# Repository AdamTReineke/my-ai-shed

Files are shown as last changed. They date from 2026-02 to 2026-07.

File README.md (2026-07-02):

# My AI Shed

## A 12x16 Shed, primarily designed by Claude

I'm building a shed and this repository documents the design.

A photo of the shed from April 13, 2026

## Table of Contents

- [0 — Shed Design](docs/0-readme.md)
- [1 — Pier Design & As-Built Details](docs/1-piers.md)
- [2 — Beam](docs/2-beam.md)
- [3 — Floor Joists](docs/3-joists.md)
- [4 — Wall Framing](docs/4-walls.md)
- [5 — Wall Assembly Layers](docs/5-wall-layers.md)
- [6 — Trusses (Queen-Post Design)](docs/6-trusses.md)
- [7 — Roof](docs/7-roof.md)
- [8 — Fastener Schedule](docs/8-fasteners.md)
- [9 — Interior Finishings](docs/9-finishings.md)
- [10 — Stairs & Landing](docs/10-stairs.md)
- [11 — Trades & Mechanical](docs/11-trades.md)
- [12 — Metal Roof](docs/12-metal-roof.md)
- [13 — Siding Installation](docs/13-siding.md)
- [A1 — Errata & Documentation Inconsistencies](docs/A1-errata.md)
- [A2 — Eaves & Overhangs](docs/A2-eaves-proposal.md)
- [A3 — Batten & Purlin Grid](docs/A3-purlin-proposal.md)
- [Images](images.md)

## Screenshots of the Model

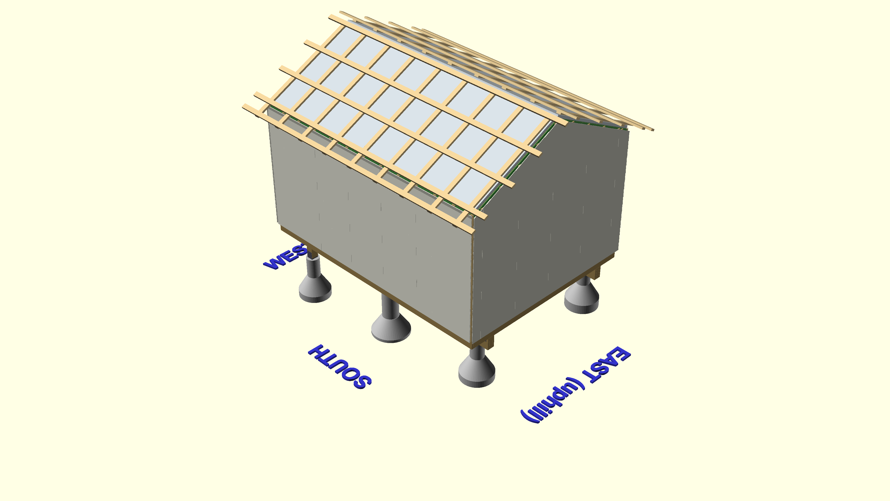
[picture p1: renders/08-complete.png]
screenshot of the OpenSCAD rendering of the shed


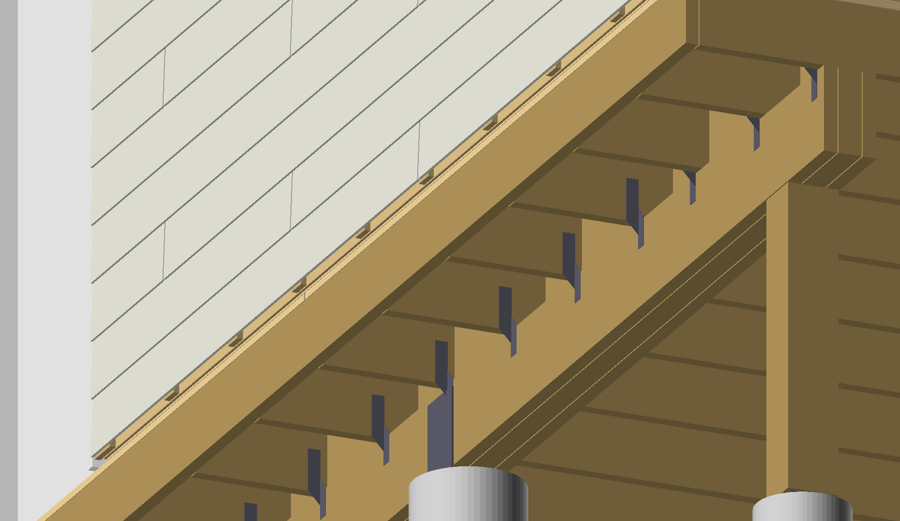
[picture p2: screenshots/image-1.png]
screenshot from below the floor plane showing some of the joist layout, ties, etc and the siding on the walls


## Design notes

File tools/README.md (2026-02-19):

# Tools

Node.js scripts for generating data files and processing output. Run from the project root (`shed/`).

## siding-cuts.js

Generates the HardiePlank lap siding cut list.

```bash
node tools/siding-cuts.js             # print cut list to console
node tools/siding-cuts.js --json      # JSON output
node tools/siding-cuts.js --scad      # also writes model/siding_data.scad
```

## generate-truss-data.js

Generates polyhedron geometry for the queen-post trusses. Output is used by `model/trusses.scad`.

```bash
node tools/generate-truss-data.js     # writes model/truss_data.scad
```

## generate-end-truss-data.js

Generates polyhedron geometry for the end trusses and gable ladder framing. Output is used by `model/trusses.scad`.

```bash
node tools/generate-end-truss-data.js  # writes model/end_truss_data.scad
```

## parse-cutlist.js

Parses OpenSCAD console output (captured to `model/openscad-output.txt`) and aggregates the cut list into `model/cutlist.csv`.

```bash
node tools/parse-cutlist.js
```

To capture OpenSCAD output: run OpenSCAD with the echo statements enabled, copy the console output to `model/openscad-output.txt`, then run this script.

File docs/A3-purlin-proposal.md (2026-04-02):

# A3 — Batten & Purlin Grid

This document describes the two-layer roof grid that sits on top of the insulated Zip roof deck. It assumes the Zip sheathing and 2" polyiso foam are already installed per A2.

**Assembly order**: Zip roof deck → 2" polyiso (A2) → **battens → purlins** → metal roofing

---

## Coordinate System & Key Dimensions

| Reference | Value |
|---|---|
| Shed length (E-W) | 192" (16') |
| Shed width (N-S) | 144" (12') |
| Roof pitch | 6/12 (26.57°) |
| Rafter slope length (wall face to ridge) | 80.5" |
| Truss spacing | 24" o.c., 9 trusses |
| Target overhang (all sides) | 12" horizontal |

---

## Layer 1: Battens (up the slope, aligned with trusses)

Battens are the vertical members running from near the ridge down past the wall. They sit directly on the foam.

| Parameter | Value |
|---|---|
| Material | 2×4 SPF, installed **flat** (3.5" wide, 1.5" tall) |
| Orientation | Up the slope (parallel to rafters) |
| Spacing | 24" o.c., aligned with truss X positions |
| Ridge end | Stops **3" short of peak** (horizontal), ~3.4" along slope |
| Eave end | Extends **12" past wall** (horizontal), ~13.4" along slope |
| End battens | Inset so outer edge aligns with outer wall edge |
| Count | 9 per slope × 2 slopes = **18 battens** |

### Batten Length

```
slope_length = 72" / cos(26.57°) = 80.5"
ridge_gap_slope = 3" / cos(26.57°) = 3.4"
overhang_slope = 12" / cos(26.57°) = 13.4"
batten_length = 80.5" - 3.4" + 13.4" = 90.5"
```

~90.5" per batten — fits in 8' stock.

### Batten Attachment

- **Fastener**: #10 × 6" structural screws (e.g., GRK RSS)
- **Penetration**: 1.5" (batten) + 2" (foam) + 7/16" (Zip) + 2.0" (rafter bite) = 6.0"
- **Pattern**: 2 screws per batten where it crosses the rafter below (one crossing per batten, since they're aligned)
- **Count**: 9 battens × 2 screws × 2 slopes = **36 screws**

---

## Layer 2: Purlins (E-W, over battens)

Purlins are the horizontal members running E-W across the battens. Metal roofing screws into these.

| Parameter | Value |
|---|---|
| Material | 2×4 SPF, installed **flat** (3.5" wide, 1.5" tall) |
| Orientation | E-W (parallel to ridge) |
| Length | Two boards per row, butt-joined at center truss (96" from west end) |
| E-W extension | 12" past each gable end (configurable) |
| Total span | 192" + 24" = **216"** per row (two ~108" boards) |

### Purlin Row Positions (5 per slope)

The 5 rows are positioned relative to the ridge along the slope:

| Row | Position | Role |
|-----|---|---|
| P1 (ridge) | 3.4" from peak | Flush with top of battens; ridge cap attachment |
| P2 | ridge + 1/3 span | Field support |
| P3 | ridge + 2/3 span | Field support |
| P4 (wall) | 80.5" (at wall edge) | Transition point; overlaps roof/wall junction |
| P5 (eave) | 93.9" (at batten ends) | Flush with bottom of battens; eave attachment |

Where **span** = wall_pos − ridge_pos = 80.5" − 3.4" = 77.1", so:
- P2 = 3.4" + 25.7" = **29.1"** from peak
- P3 = 3.4" + 51.4" = **54.8"** from peak

**5 rows per slope × 2 slopes = 10 purlin rows = 20 boards**

### Purlin Attachment

Purlins sit on top of battens and are screwed down at each crossing:

- **Fastener**: #10 × 3" exterior screws
- **Pattern**: 2 screws per purlin-batten crossing
- **Crossings**: 5 rows × 9 battens × 2 slopes = 90 crossings
- **Count**: 90 × 2 = **180 screws**

---

## Plan View — One Slope

```
                    WEST                                          EAST
                    ←12"→←──────────── 192" (16') ──────────────→←12"→

Ridge (P1)          ════════════════════════════════════════════════════
                    |    |    |    |    |    |    |    |    |    |
P2 (29.1")          ════════════════════════════════════════════════════
                    |    |    |    |    |    |    |    |    |    |
P3 (54.8")          ════════════════════════════════════════════════════
                    |    |    |    |    |    |    |    |    |    |
- - - - - - - - - - wall face (80.5" down slope) - - - - - - - - - - -
P4 (wall, 80.5")    ════════════════════════════════════════════════════
                    |    |    |    |    |    |    |    |    |    |
Eave (P5, 93.9")    ════════════════════════════════════════════════════
                    ↑    ↑                                  ↑    ↑
                  end  T2                                T8  end
                 batten                                    batten

═══ = purlins (E-W, horizontal)
 |  = battens (up slope, vertical)
```

---

## Section View — Full Assembly at Eave

```
Looking east at south eave:

                ↑ ridge direction
               /
    P3 ═══════/═══════════   (purlin, over battens)
    ║║║║║║║║║/║║║║║║║║║║║   (batten, 2×4 flat on foam)
    ▓▓▓▓▓▓▓/▓▓▓▓▓▓▓▓▓▓▓▓   (2" polyiso)
    ══════/═══════════════   (Zip roof deck)
    ─────/─────────────────   (rafter)
         /
    P4 ═/═══════════════     (purlin at wall line)
    ║║║/║║║║║║║║║║║║║║║║║
    ▓▓/▓▓▓▓▓▓▓▓▓▓▓▓▓▓▓▓╗
    ═/════════════════════╗
    /──────────────────────
                           ║ wall face
    P5 ════════════════    ║ (eave purlin, on batten tips)
    ║║║║║║║║║║║║║║║║║║    ║ (batten extends 12" past wall)
                        12" out
```

---

## Materials Summary

| Component | Material | Size | Qty | Notes |
|---|---|---|-----|---|
| Battens | 2×4 SPF | 8' | 18 | 9 per slope, ~90.5" each |
| Purlins | 2×4 SPF | 9' (butt-joined at center) | 20 | 5 rows × 2 slopes × 2 halves |
| Structural screws | #10 × 6" | — | 36 | Battens into rafters through foam |
| Exterior screws | #10 × 3" | — | 180 | Purlins into battens |
| Closure strips (eave) | Foam | 18' | 2 | Match metal panel profile |
| Closure strips (ridge) | Foam | 16' | 2 | Under ridge cap |
| Ridge cap | Metal (match panels) | 16' | ~2 pcs | Overlapping at center |

---

## Installation Sequence

1. **Mark truss positions** on foam surface (24" o.c. from east end)
2. **Install battens** — 2×4 flat on foam, aligned with each truss, screwed through foam into rafter with #10 × 6" screws. Stop 3" short of peak, extend 12" past wall.
3. **Install purlins P1–P5** — 2×4 flat over battens, running E-W. Two boards per row, butt-joined at center truss. Extend 12" past each gable end. Screw into battens with #10 × 3" screws.
4. **Install drip edge** (Type D/F at eaves for gutters)
5. **Install metal roofing** — panels run ridge to eave, screw into purlins
6. **Install rake drip edge** — over panel edges
7. **Install ridge cap** with closure strips

---

## Open Questions

1. **Metal roofing profile** — exposed fastener vs. standing seam determines exact purlin spacing requirements and closure strip profile.

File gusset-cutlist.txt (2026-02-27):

Gusset Plate Cut List - 1/2" Plywood (48"x96" sheets)
============================================================
Total pieces: 98 (14x 12x20, 84x 10x8)
Sheets required: 3

Sheet 1  (88.5% utilization)
  Summary: 14x 12x20, 9x 10x8
  Layout:
    12x20  at ( 0,  0)  cut 12"x20"
    12x20  at (12,  0)  cut 12"x20"
    12x20  at (24,  0)  cut 12"x20"
    12x20  at (36,  0)  cut 12"x20"
    12x20  at ( 0, 20)  cut 12"x20"
    12x20  at (12, 20)  cut 12"x20"
    12x20  at (24, 20)  cut 12"x20"
    12x20  at (36, 20)  cut 12"x20"
    12x20  at ( 0, 40)  cut 12"x20"
    12x20  at (12, 40)  cut 12"x20"
    12x20  at (24, 40)  cut 12"x20"
    12x20  at (36, 40)  cut 12"x20"
    12x20  at ( 0, 60)  cut 12"x20"
    12x20  at (12, 60)  cut 12"x20"
    10x8   at (24, 60)  cut 8"x10"
    10x8   at (32, 60)  cut 8"x10"
    10x8   at (40, 60)  cut 8"x10"
    10x8   at ( 0, 80)  cut 8"x10"
    10x8   at ( 8, 80)  cut 8"x10"
    10x8   at (16, 80)  cut 8"x10"
    10x8   at (24, 80)  cut 8"x10"
    10x8   at (32, 80)  cut 8"x10"
    10x8   at (40, 80)  cut 8"x10"

Sheet 2  (93.8% utilization)
  Summary: 54x 10x8
  Layout:
    10x8   at ( 0,  0)  cut 8"x10"
    10x8   at ( 8,  0)  cut 8"x10"
    10x8   at (16,  0)  cut 8"x10"
    10x8   at (24,  0)  cut 8"x10"
    10x8   at (32,  0)  cut 8"x10"
    10x8   at (40,  0)  cut 8"x10"
    10x8   at ( 0, 10)  cut 8"x10"
    10x8   at ( 8, 10)  cut 8"x10"
    10x8   at (16, 10)  cut 8"x10"
    10x8   at (24, 10)  cut 8"x10"
    10x8   at (32, 10)  cut 8"x10"
    10x8   at (40, 10)  cut 8"x10"
    10x8   at ( 0, 20)  cut 8"x10"
    10x8   at ( 8, 20)  cut 8"x10"
    10x8   at (16, 20)  cut 8"x10"
    10x8   at (24, 20)  cut 8"x10"
    10x8   at (32, 20)  cut 8"x10"
    10x8   at (40, 20)  cut 8"x10"
    10x8   at ( 0, 30)  cut 8"x10"
    10x8   at ( 8, 30)  cut 8"x10"
    10x8   at (16, 30)  cut 8"x10"
    10x8   at (24, 30)  cut 8"x10"
    10x8   at (32, 30)  cut 8"x10"
    10x8   at (40, 30)  cut 8"x10"
    10x8   at ( 0, 40)  cut 8"x10"
    10x8   at ( 8, 40)  cut 8"x10"
    10x8   at (16, 40)  cut 8"x10"
    10x8   at (24, 40)  cut 8"x10"
    10x8   at (32, 40)  cut 8"x10"
    10x8   at (40, 40)  cut 8"x10"
    10x8   at ( 0, 50)  cut 8"x10"
    10x8   at ( 8, 50)  cut 8"x10"
    10x8   at (16, 50)  cut 8"x10"
    10x8   at (24, 50)  cut 8"x10"
    10x8   at (32, 50)  cut 8"x10"
    10x8   at (40, 50)  cut 8"x10"
    10x8   at ( 0, 60)  cut 8"x10"
    10x8   at ( 8, 60)  cut 8"x10"
    10x8   at (16, 60)  cut 8"x10"
    10x8   at (24, 60)  cut 8"x10"
    10x8   at (32, 60)  cut 8"x10"
    10x8   at (40, 60)  cut 8"x10"
    10x8   at ( 0, 70)  cut 8"x10"
    10x8   at ( 8, 70)  cut 8"x10"
    10x8   at (16, 70)  cut 8"x10"
    10x8   at (24, 70)  cut 8"x10"
    10x8   at (32, 70)  cut 8"x10"
    10x8   at (40, 70)  cut 8"x10"
    10x8   at ( 0, 80)  cut 8"x10"
    10x8   at ( 8, 80)  cut 8"x10"
    10x8   at (16, 80)  cut 8"x10"
    10x8   at (24, 80)  cut 8"x10"
    10x8   at (32, 80)  cut 8"x10"
    10x8   at (40, 80)  cut 8"x10"

Sheet 3  (36.5% utilization)
  Summary: 21x 10x8
  Layout:
    10x8   at ( 0,  0)  cut 8"x10"
    10x8   at ( 8,  0)  cut 8"x10"
    10x8   at (16,  0)  cut 8"x10"
    10x8   at (24,  0)  cut 8"x10"
    10x8   at (32,  0)  cut 8"x10"
    10x8   at (40,  0)  cut 8"x10"
    10x8   at ( 0, 10)  cut 8"x10"
    10x8   at ( 8, 10)  cut 8"x10"
    10x8   at (16, 10)  cut 8"x10"
    10x8   at (24, 10)  cut 8"x10"
    10x8   at (32, 10)  cut 8"x10"
    10x8   at (40, 10)  cut 8"x10"
    10x8   at ( 0, 20)  cut 8"x10"
    10x8   at ( 8, 20)  cut 8"x10"
    10x8   at (16, 20)  cut 8"x10"
    10x8   at (24, 20)  cut 8"x10"
    10x8   at (32, 20)  cut 8"x10"
    10x8   at (40, 20)  cut 8"x10"
    10x8   at ( 0, 30)  cut 8"x10"
    10x8   at ( 8, 30)  cut 8"x10"
    10x8   at (16, 30)  cut 8"x10"

============================================================
Total sheet area: 96.0 sq ft
Used area:        70.0 sq ft
Waste:            26.0 sq ft (27.1%)

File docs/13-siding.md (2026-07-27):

# Siding Installation

Process guide for hanging the HardiePlank lap siding over the rainscreen. Design background is in [5-wall-layers.md](5-wall-layers.md); fastener spec is in [8-fasteners.md](8-fasteners.md) §16. Cut list comes from `node tools/siding-cuts.js`.

## Where This Starts

Assumed already done before siding day:

- [ ] Zip sheathing up on all four walls, all seams taped and rolled
- [ ] Door installed, trimmed, and caulked (✓ done — siding butts to the existing trim)
- [ ] Z-flashing (or peel-and-stick) at the base of the Zip, lapping down over the rim/bottom plate

## The Stack (inside → out)

```
Zip sheathing (WRB)
  → 1×3 PT furring, vertical @ 16" o.c. over studs   (¾" rainscreen gap)
    → bug mesh closing the bottom of the gap
      → ripped HardiePlank starter strip
        → HardiePlank lap siding, 6.25" exposure, blind-nailed
          → metal outside corners, one per corner per course
```

Total buildup off the Zip face: ¾" furring + 5/16" plank ≈ **1-1/16"**. Remember this number — every screw that mounts anything to the finished wall has to cross it before reaching wood.

---

## Step 1 — Furring (1×3 PT, vertical)

- One strip over **every stud line**, 16" o.c., plus a strip at each **corner** (both faces of the corner need an edge to nail to) and tight to each side of the **door trim**.
- Fasten with **#8 (or #9) × 2½"–3½" PT-rated screws** into the studs, ~16" o.c. vertically. Screws, not nails — the furring holds the whole siding plane ¾" off the wall, so wind suction loads it in withdrawal, and a screw lets you back a bowed strip out and reset it.
  - **Coating:** must be rated for ACQ/PT contact — 305 stainless, or a coated structural/deck screw carrying a PT rating (GRK, Spax, Deckmate). Plain steel and electro-galvanized corrode out. These screws never touch the fiber cement, so unlike the siding nails they don't have to be stainless.
  - **Length:** ¾" furring + 7/16" Zip = **1.19" before the stud**, so 2½" buys 1.31" of thread and 3½" buys 2.31". Anything in that band works; 3" is the spec in [8-fasteners.md](8-fasteners.md) §16 and the best all-rounder. Keep the longest screws for the field — at corners and door jambs you're driving near stud edges, where an over-long screw can exit the side or reach the door jamb.
  - Don't drop below a #8 shank — a trim-head screw's head is too small to hold ¾" PT against the wall under suction.
- Check the furring plane for flatness as you go — a bowed strip telegraphs through every course above it. Shim or swap bad strips now, not later.
- **Extra furring where butt joints land.** Every plank butt joint must be backed by a furring strip. The cut list puts joints on stud lines, so the standard layout covers it — but if you improvise a joint mid-bay, add a strip behind it first.
- **Mark gutter bracket and electrical box locations on the Zip now** (see Steps 6–7) and add backing before the siding hides everything.

Leave the top of the gap open — top venting differs by wall, see **Top-of-Wall Transitions** below. The bottom gets closed next.

## Step 2 — Bug Mesh at the Bottom

Close the bottom of the ¾" gap so it vents but doesn't host wasps:

- Run the mesh (Cor-A-Vent SV-3 or insect screen strip) along the bottom of the wall, spanning the gap between the Zip face and the back of the siding plane.
- If using screen roll rather than a rigid vent strip: staple one edge to the Zip just above the Z-flashing, wrap it forward under the furring bottoms, and let the siding's first course pin the front edge. Don't block the airflow — the mesh breathes, a solid closure doesn't.
- Trim flush; it shouldn't be visible below the finished siding.

## Step 3 — Rip the Starter Strip

The starter strip kicks the first course out to the same angle as every other course (each normal course sits on the 2" of plank below it; course 1 has nothing under it without a starter).

- Rip **1¼"-wide strips** from one HardiePlank. One 12' plank ripped into 6 strips yields 72 lf — the perimeter needs ~53 lf, so **one plank does the whole shed** with spare.
- Cut with a circular saw + fiber-cement (PCD) blade against a rip guide, **outdoors, upwind, with an N95/P100 on** — fiber cement dust is crystalline silica. Score-and-snap doesn't work well for long rips.
- Nail the strips along the very bottom of the furring, bottom edges flush with the furring bottoms, one nail per strip per furring line.

## Step 4 — Layout

- **Story pole / chalk lines:** mark course tops every **6.25"** up from the first-course line on the corner furring strips and snap lines, or make a story pole and transfer marks. 16 courses reach the top of the 8' wall (16 × 6.25" = 100", so the top course gets ripped down — see Step 5).
- **First course:** bottom edge hangs **~¼" below the starter strip** to form a drip over the Z-flashing. Keep the bottom edge at least 1" clear of any horizontal surface and 6" clear of grade (the floor is up on piers, so this should be automatic — verify at the low corner).
- **Level check:** the first course sets every course above it. Get it dead level with a laser or 8' level before nailing off.

## Step 5 — Hang the Planks

Work bottom-up, one course at a time around the building. The cut list (`node tools/siding-cuts.js`) gives every piece per wall per course with stagger already worked out — cut a few courses ahead, label the backs (`S-3-1` = south, course 3, piece 1).

**Nailing** (per [8-fasteners.md](8-fasteners.md) §16):
- **3" stainless ring-shank**, blind-nailed **1" down from the top edge**, at **every furring strip** (16" o.c.).
- Keep nails **⅜" or more from plank ends**.
- Drive **flush, not countersunk** — an overdriven nail crushes the fiber cement and loses holding power. Set the gun pressure on a scrap first.

**Butt joints:**
- Land on furring, **⅛" gap**, caulked with paintable sealant after hanging.
- Prime every field-cut end before the piece goes up (touch-up primer or exterior acrylic paint — cut edges are bare cement).

**Metal outside corners:**
- One corner piece **per corner per course** (64 total). Hang the planks on both adjoining walls first, stopping each plank ⅛" shy of the corner (the cut list already builds this in), then slip the corner cap over both plank ends and nail through its top flange. The next course's planks and cap cover the nailing.
- E/W wall planks wrap over the N/S wall buildup at corners — that's why E/W courses are 146⅞", not 144" (one plank + a short piece per course, per the cut list).

**North wall / door:**
- Planks butt to the existing door trim with a **⅛" caulked gap** — do not nail within 2" of the trim edge.
- Courses 0–12 are split by the door: long run west of the door (has a staggered butt joint), short 13⅜" pieces between door trim and the east corner. Courses 13–15 run over the door full-width.
- Confirm there's a **metal drip cap over the door head trim** before siding above it; the course above the door laps over the drip cap flange, with a ¼" air gap above the horizontal leg (don't caulk that gap — it drains).

**Top course (N/S eave walls):**
- 16 courses × 6.25" overshoots the 96" wall by ~4" — rip the top course to end at the top of the wall Zip. Top-of-gap detail: see **Top-of-Wall Transitions** below.
- A ripped top course loses its blind-nail zone: **face-nail** it (2 nails per furring, ¾" from the top edge), and dab the heads with sealant + touch-up paint.

**Gable ends (E/W walls):**
- The cut list covers only the 16 rectangular courses — the gable triangles are measure-in-place. Continue courses up the gable, cutting plank ends at the roof pitch angle (**6/12 = 26.6°**).
- Gable planks need furring backing on the end-truss framing — add vertical 1×3 over the gable studs/webs before starting the triangle.
- Hold the top cuts **~¾" below the rake underside** to form the exhaust slot — see **Top-of-Wall Transitions** below. Cut edges must be primed.

### Top-of-Wall Transitions (Rainscreen Exhaust)

The two wall types terminate differently because the overhangs are built differently (no rafter tails — the eave is battens extended past the wall over the polyiso, open soffit, per [A2-eaves-proposal.md](A2-eaves-proposal.md)).

**N/S eave walls — closure block between battens, sealed under P4.** The P4 purlin row lands directly over the wall line (per [A3-purlin-proposal.md](A3-purlin-proposal.md)). A block in each batten bay — face at the furring plane, top edge tight under P4 — terminates the siding, covers the exposed deck/foam edges, and seals the junction so the rainscreen exhaust turns inboard and vents at the ridge instead of spilling out under the open soffit:

```
   slope ↗  metal panel
  ═══════════════════════════════════
       [P4 purlin] ← at the wall line, on the battens
   batten ─────────────────────────►  extends 12" past wall
   ░░ 2" polyiso ░░│ ┌───┐
   ── Zip deck ────│¾│blk│ ← block fills the batten bay, top edge
      heel blocking│"│   │   beveled 26.6°, tight under P4
      / top plate  │g│   │
   wall Zip ──────►│a│───┘
                   │p├───┐
                   │ │sid│ ← ripped top course laps block bottom ~1",
                   │ │   │   face-nailed into the block
```

- Battens are 2×4 flat (3.5" wide) at 24" o.c., so the bays match the 2×2 eave-blocking cut list: **six 20.5" blocks + two 19.75" end blocks per wall** (16 total). Height is measure-in-place: from ~1" below the siding top line up to the underside of P4, top edge **beveled 26.6°** to seat flat under it. Likely 1×6 or 1×8 stock — PT like the furring, or primed.
- Install each block on **¾" spacers** (furring offcuts) with 3" screws into the heel blocking/top plate — its face lands flush with the furring plane. Ends can be toe-screwed into the batten sides. Do not fill the ¾" standoff — a block tight to the Zip corks the rainscreen.
- Exhaust path: up the wall gap → behind the block → inboard along the between-batten channel → under the panels to the ridge vent. The bay is closed on all sides (battens flanking, P4 above, block in front), so no air or bugs pass to/from the open soffit.
- **No bug screen needed** — the circuit is closed: bottom mesh in, ridge profile vent out. The only residual route is the panel corrugation flutes crossing over the top of P4 from the overhang — the same exposure the roof channel already has by design. Add a mesh strip behind the blocks if that bothers you.
- Run the ripped top siding course up over the block's bottom edge and **face-nail into the block** (it doubles as the top-course nailer). No caulk along the top edge.
- Bonus: the block shields the bare roof-deck and polyiso edges at the wall line from UV, mice, and woodpeckers.

**E/W gable ends — terminated slot vent under the rake.** The gable gap cannot join the roof channel — the Zip deck edge, foam edge, and butyl-sealed gable trim close it off at the rake. It's a dead-end circuit: intake at the bottom mesh, exhaust through a screened slot under the rake overhang:

- Cut furring tops parallel to the rake, **~¾" below the underside of the rake structure** (foam/batten edge, or barge board if installed).
- Cut the siding top edges to the same line — this leaves a continuous downward-facing slot under the 12" rake overhang. Rain-protected; anything that blows in drains out the bottom mesh.
- Screen the slot the same way — mesh stapled to the Zip, folded out over the furring tops.
- **Do not caulk** the siding-to-rake edge.

## Step 6 — Electrical Mounting Blocks (outlets & lights)

Install the siding mounting blocks **as the courses reach them**, not after:

1. Before siding (Step 1), confirm each box location has **solid backing** — a stud/furring line, or add a horizontal 1×3 block between furring strips (leave ½" drainage gaps at its ends so it doesn't dam the rainscreen).
2. Drill the wire penetration through the Zip, pull the cable, and **seal the penetration** with Zip tape or sealant — the WRB is the water barrier, not the block.
3. When the course row reaches the block height, fasten the block to the backing, then cut the surrounding planks to it with a **⅛" caulked gap** on sides and bottom.
4. **Flash the top:** the block's built-in flange or a strip of Zip tape/drip cap behind the course above, so water sheds over the block face rather than behind it.

## Step 7 — Gutters on the Wall

Wall-mounted brackets have two problems on a rainscreen wall: the fastener has to reach real wood, and it must not crush the siding into the ¾" air gap.

- **Land every bracket on a stud line** (which is also a furring line — 16" o.c.). Marks made on the Zip in Step 1 transfer up via the furring strips.
- **Fastener:** stainless or coated structural screw long enough for the buildup — 5/16" plank + ¾" furring + 7/16" Zip = 1.5" before wood, so a **3½"–4" screw** gets 2"+ into the stud.
- **Pre-drill the HardiePlank** at each screw location (fiber cement cracks if a lag wanders) and snug the screw until the bracket bears — **stop before the plank deflects**. Because the bracket lands over a furring strip, the sandwich is solid there; that's the whole reason for hitting the stud lines.
- Bed each bracket in a dab of exterior sealant and cap the screw heads with the same. Any hole through the siding that misses (there's always one) gets filled with sealant immediately.
- If a bracket must land between studs, add horizontal blocking behind the siding **before** that course goes up — there is no fixing this after.

## Step 8 — Caulk and Paint

- Caulk: all butt joints, siding-to-door-trim, siding-to-mounting-block sides/bottoms. **Do not caulk** the bottom of any lap, the gap above the door drip cap, or the top/bottom rainscreen vents — those all drain or breathe by design.
- Paint: planks come pre-primed; finish-coat all faces with exterior acrylic. Every field cut should already have primer from Step 5 — the finish coat goes over it.

---

## Cut List & Materials

Full per-piece cut list: `node tools/siding-cuts.js` (77 stock planks, 141 pieces, stagger and corner gaps computed). Quantities table is in [5-wall-layers.md](5-wall-layers.md), with these deltas:

| Item | Change |
|---|---|
| HardiePlank starter strip (5 × 12') | **Not needed** — rip 1 plank into 1¼" strips instead |
| Aluminum outside corners | 64 pieces (4 corners × 16 courses), plus gable-course corners are N/A (gables have no outside corners) |
| Structural screws for gutter brackets | 3½"–4" SS/coated, qty per bracket count |
| Siding mounting blocks | Per fixture count (outlets + lights) |

## Safety Notes

- **Silica dust:** all fiber-cement cutting outdoors, upwind, N95/P100 respirator, PCD blade or fiber-cement shears. Shears make no dust — prefer them for notches and short cuts.
- HardiePlank is floppy and snaps under its own weight — carry 12' planks on edge, two people or a plank carrier.

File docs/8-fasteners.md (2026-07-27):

# 8 — Fastener Schedule

All fasteners in contact with PT lumber or exterior exposure must be **stainless steel** or **hot-dip galvanized (HDG)**. ACQ-treated wood corrodes plain steel and electroplated (zinc-plated) fasteners. Stainless is preferred for longevity (50-year design life); HDG is acceptable for interior/protected connections.

**Nail gun note:** Most connections below call for hand-nailing or a framing nailer. For 16d HDG nails, a full-head framing nailer (e.g., Bostitch F21PL) is ideal. Ring-shank nails for sheathing can use a coil nailer. Verify your nailer accepts HDG/SS nail strips before buying.

---

## 1. Pier to Beam/Post — 6x ABU66SS

Simpson ABU66SS stainless adjustable post base, one per pier (6 total).

- 5/8" × 6" SS Titen HD screw anchor (Simpson THDB62600H4SS, 304 stainless)
  - Qty: 1 per bracket × 6 piers = 6 total
  - In contact with: cured concrete, SS bracket
  - Drill 5/8" hole with carbide bit (hole diameter = nominal diameter for Titen HD);
    - Min hole depth 6" per spec sheet for 5-1/2" nominal embedment (overdrill 1/2" past embedment to collect tapping dust)
  - Drive with 15/16" wrench; max installation torque 85 ft-lbf; min concrete thickness 8-1/2"
  - Per ABA/ABU/ABW spec sheet: 5/8" anchor required for ABU66
    - Stack above concrete: ABU66SS base plate (12 ga ~0.105") + included washer (~0.065") + hex head (~0.19") ≈ 0.36";
    - 6" anchor gives ~5.64" embedment vs. 5-1/2" nominal ✓
  - Min edge distance from pier edge: 1-3/4" (absolute minimum); 6" for full rated load capacity.
    - TODO: Measure the final installed location and calculate the derating since we'll be off-center on the 12" pillar.
  - Purchased (6):
    - THDB62600H4SS - 5/8" x 6" Strong-Tie Titen HD Screw Anchor, 304 Stainless Steel

- 1/2" × 6.5" SS hex bolt + nut + 2 washers
  - (Note: order the 7" version. Only quarter inch remaining threads makes me nervous)
  - Qty: 2 per bracket × 6 piers = 12 sets
  - In contact with: PT Hem-Fir beam/post, SS bracket
  - Material depth: 6×6 post/beam = 5.5" actual + two 12-ga flanges (~0.21" total) + 2 washers (~0.13") + 1/2" nut (~0.44") = ~6.28" stack; 6.5" provides ~0.22" thread past nut for adequate engagement. Must be structural through-bolt per ABU66SS spec (not lag screw or carriage bolt).
  - Through ABU side flanges and full post/beam width; SS required for PT contact
  - Purchased 2026-02-19 (McMaster-Carr order 3038177):
    - (x12) Super-Corrosion-Resistant 316 Stainless Steel Hex Head Screw, 1/2"-13 Thread Size, 7" Long, Partially Threaded
      - https://www.mcmaster.com/92186A738/ (1 @ 4.37) ✓
    - (x24, extra 1) Highly Corrosion-Resistant 316 Stainless Steel Washer for 1/2" Screw Size, General Purpose, 0.531" ID
      - https://www.mcmaster.com/90107A033/ (25 @ 10.24) ✓
    - (x12, extra 3) Highly Corrosion-Resistant 316 Stainless Steel Hex Nut, 1/2"-13 Thread Size
      - https://www.mcmaster.com/94804A340/ (10 @ 4.71) ✓
      - https://www.mcmaster.com/94819A055/ (5 @ 3.22) ✓

---

## 2. Post to Beam — 2x CC66 (west posts only)

Simpson CC66 painted column cap, one per west post (2 total, already purchased at $132.73 each). Connects beam to top of 6×6 post.

- 5/8" × 7" HDG machine bolt + nut + 2 washers (4x beam side + 2x post side * 2 posts = 12 sets)
  - In contact with: PT Hem-Fir built-up beam, painted steel cap
    - HDG required for PT contact
  - Material depth:
    - 3-ply beam 5.5" + two 7-ga flanges (~0.36") + 2 washers (~0.17") + 5/8" nut (~0.55") = ~6.58" stack;
    - 7" provides ~0.42" thread past nut for adequate engagement.
    - No 7" available, use 8". Do not cut the ends to maintain coating.
  - Required strength: All references to bolts are for structural quality through bolts (not lag screws or carriage bolts) equal to or better than ASTM A307, Grade A.
  - Purchased 2026-02-19 (McMaster-Carr order 3038177):
    - (req 12) Hot-Dipped Galvanized Steel Hex Head Screw, Low-Strength, 5/8"-11 Thread Size, 8" Long (1.75" min threads)
      - meets: ASME B18.2.1, ASTM A307
      - McM https://www.mcmaster.com/95373A258 ✓
    - (req 12, x25, extra 13) Hot-Dipped Galvanized Low-Strength Steel Hex Nut, SAE Grade 2, 5/8"-11 Thread Size
      - McM https://www.mcmaster.com/90371A050 ✓
    - (req 24, x50, extra 26) Corrosion-Resistant Galvanized Steel Structural Washer for 5/8" Screw Size, 0.688" ID, 1.312" OD
      - McM https://www.mcmaster.com/98119A035/ ✓ (ordered 2 packs of 25 = 50 total)

---

## 3. Beam Lamination — 2 beams × 16'

3-ply built-up beam: 2×10 + 3×10 + 2×10 (5.5" × 9.25"), per [2-beam.md](2-beam.md).

- 1/2" × 6.5" HDG hex bolt + nut + 2 washers
  - Qty: 8 per beam × 2 beams = 16 sets total
  - In contact with: PT Hem-Fir 2×10 outer plies and PT Hem-Fir 3×10 center ply, full 5.5" width
  - Stack: beam 5.5" + two washers (~0.13") + 1/2" nut (~0.44") = ~6.07"; 6.5" bolt provides ~0.43" thread past nut ✓
  - Lateral design value (NDS Table 11A, 1/2" bolt, double shear, Hem-Fir G=0.43): Z ≈ 2,100 lb/bolt; 16 bolts × 2,100 = 33,600 lb total capacity vs. 3,111 lb max shear — 18% utilization ✓
  - Stagger top/bottom rows at 24" o.c.; edge distance ≥ 1.5" per NDS 11.5.1; drill through 5.5" with a long-shank 1/2" bit and clamp all three plies in one pass
  - HDG required — all plies are PT Hem-Fir (ACQ treatment)
  - Purchased 2026-02-19 (McMaster-Carr order 3038177):
    - (req 16) Hot-Dipped Galvanized Steel Hex Head Screw, Low-Strength, 1/2"-13 Thread Size, 6-1/2" Long
      - https://www.mcmaster.com/95373A247 1 @ 3.68 ✓
    - (req 16, x50, extra 34) Hot-Dipped Galvanized Low-Strength Steel Hex Nut, SAE Grade 2, 1/2"-13 Thread Size
      - https://www.mcmaster.com/90371A045 50 @ 14.80 ✓
    - (req 32) Corrosion-Resistant Galvanized Steel Structural Washer for 1/2" Screw Size, 0.531" ID, 1.062" OD
      - https://www.mcmaster.com/98119A033/ 50 @ 9.68 ✓

---

## 4. Joist to Beam — 26x H2.5ASS Hurricane Ties

Simpson H2.5ASS (18-ga stainless), one per joist-beam intersection. Joists sit on top of beams (joist-over-beam framing). 13 joists × 2 beams = 26 ties.

- 0.131" × X" SS joist hanger nail
  - In contact with: PT Hem-Fir joist face, PT Hem-Fir beam face, SS tie
  - Joist depth is 1.5", Beam depth is 5.5"
  - Qty: 5 long + 5 short per tie × 26 ties = 130 short + 130 long total
  - 5 into joist face + 5 into beam top; SS required — tie is stainless and lumber is PT
  - (Not at Home Depot or McMaster Carr. Drive with pneumatic palm nailer.)
  - (155 @ $23.36) 1.5" https://www.fastenersplus.com/products/simpson-ssna8-8d-x-1-1-2-ring-shank-connector-nail-316-stainless-steel-1-lb-tub
  - (94 @ $24.12) 2.5" https://www.fastenersplus.com/products/simpson-ssa8d-8d-x-2-1-2-ring-shank-connector-nail-316-stainless-steel-1-lb-tub

---

## 5. Rim Joists

2×8 PT rim joists at east and west ends (x=0" and x=192").

- 16d HDG common nail (3.5" × 0.162")
  - Qty (rim to beam): 3 per beam crossing × 2 beams × 2 rims = 12 nails
  - Qty (rim to field joist): 3 per joist end × 11 joists × 2 rims = 66 nails
  - Total: ~78 nails
  - In contact with: PT Hem-Fir rim joist, PT Hem-Fir beam (toe-nail) and PT Hem-Fir field joists (end-nail)
  - Material depth (rim to beam, toe-nail): rim sits on top of beam; nail driven at ~30° through rim into beam side grain; 3.5" nail gives ~2.0" penetration into beam — correct
  - Material depth (rim to field joist, end-nail): rim joist 1.5" + 2.0" penetration into joist end grain = 3.5" — correct
  - HDG required throughout — all lumber is PT
  - Purchased 2026-02-20 (Home Depot): Grip-Rite 16d 3-1/2" HDG Smooth Shank Common Nails, 2 × 1 lb (~94 nails). Need 78. ✓

---

## 6. Blocking at Beam Lines — 24 blocks

2×8 PT blocks (14.5" each) between joists at each beam line, per [3-joists.md](3-joists.md).

- 8d HDG common nail (2.5" × 0.131") — **substituting 3" × 0.131" HDG ring-shank**
  - Qty: 6 per block (3 per end) × 24 blocks = 144 nails
  - In contact with: PT Hem-Fir block, PT Hem-Fir joist
  - Material depth: block is 1.5" wide (2×8); toe-nail driven at ~30° through block face into joist face (1.5"); effective penetration ~1.5"+ into joist — 3" nail is longer than the 2.5" IRC minimum, acceptable for toe-nailing
  - Toe-nail each end per IRC Table R602.3(1); HDG required — all lumber is PT
  - Purchased 2026-02-20 (Home Depot): DeWalt 3" .131 Ring Shank HDG Framing Nails, 2 × 2,000 ct (DWRHS10DR131G). Used across §6, §7, §10, §13 — see those sections. ✓

Alternative: Simpson A35 framing angles (2 per block = 48 angles), each taking (4) 10d × 1.5" HDG nails. Stronger but adds cost and complexity — toe-nailing is standard and adequate.

---

## 7. Subfloor — 3/4" Advantech to Joists

6 sheets of 3/4" Advantech T&G, glued and nailed.

- 8d ring-shank HDG nail (2.5" × 0.131") — **substituting 3" × 0.131" HDG ring-shank**
  - Qty: ~100 per sheet × 6 sheets = ~600 nails
  - In contact with: PT Hem-Fir joists and blocking (below), Advantech OSB panel (above)
  - Material depth: 3/4" Advantech + 2.25" penetration into joist = 3" — exceeds 1.5" IRC minimum; acceptable
  - Panel edges over joists/blocking at 6" o.c.; field at 12" o.c. into joists. Ring-shank provides better withdrawal resistance. HDG required — joists are PT.
  - Plus: construction adhesive (PL Premium or Liquid Nails Subfloor) on joist tops before setting panels; reduces squeaks and increases diaphragm stiffness.
  - Purchased 2026-02-20 (Home Depot): DeWalt 3" .131 Ring Shank HDG Framing Nails (shared pool with §6, §10, §13). ✓

---

## 8. Wall Bottom Plate to Subfloor/Rim

KD Hem-Fir 2×6 bottom plates nailed down through subfloor into rim joists and joists below. The shed is elevated on piers — no ground contact — so the bottom plate is standard (non-PT) lumber.

- 16d bright common nail (3.5" × 0.162")
  - Qty: ~42 nails (56 lf perimeter ÷ 16" spacing), staggered side to side
  - In contact with: KD Hem-Fir 2×6 bottom plate, Advantech subfloor (above), PT Hem-Fir rim joist/joists (below)
  - Material depth: bottom plate 1.5" + 3/4" Advantech + 1.25" into rim/joist = 3.5" — correct; nail fully penetrates plate and subfloor with 1.25" into framing below (IRC minimum for this connection)
  - Bright (plain steel) is acceptable — bottom plate is non-PT. At door opening, cut plate after wall is raised.
  - Purchased 2026-02-20 (Home Depot): Grip-Rite 16d 3-1/2" Bright Smooth Common Nails, 1 lb + 2 × 5 lb = ~11 lbs (~517 nails). Used across §8, §9, §14. Need ~620 total — buy one more 1-lb box (~47 nails). ✓ (short ~100)

---

## 9. General Wall Framing — 2×6 Studs at 16" o.c.

Standard platform framing nailing schedule per IRC Table R602.3(1). All connections in this section use bright (plain steel) common nails — studs and top plates are kiln-dried Hem-Fir (non-PT) and are protected from weather once sheathed.

- 16d bright common nail (3.5" × 0.162") — top plate to stud, end-nail
  - Qty: 2 per stud; ~40 studs = ~80 nails
  - In contact with: KD Hem-Fir top plate, KD Hem-Fir stud end grain
  - Material depth: plate 1.5" + 2.0" into stud end grain = 3.5" — correct
  - Through plate into stud

- 16d bright common nail — bottom plate to stud, end-nail
  - Qty: 2 per stud; ~40 studs = ~80 nails
  - In contact with: KD Hem-Fir stud end grain, KD Hem-Fir bottom plate — both are non-PT; bright is acceptable throughout
  - Through stud into plate

- 16d bright common nail — stud to stud (corner/partition), face-nail
  - Qty: at 24" o.c. for doubled studs
  - In contact with: KD Hem-Fir studs

- 16d bright common nail — double top plate splice and corners
  - Qty: at 16" o.c.; stagger joints min 48" from wall joints; overlap min 24" past corner
  - In contact with: KD Hem-Fir top plates

- 16d bright common nail — header to king stud, end-nail
  - Qty: 4 per end, each side of header
  - In contact with: KD Hem-Fir header, KD Hem-Fir king stud

- 16d bright common nail — jack stud to king stud, face-nail
  - Qty: at 12" o.c., full height of jack
  - In contact with: KD Hem-Fir jack and king studs

- 16d bright common nail — cripple to header, end-nail
  - Qty: 2 per cripple above header
  - In contact with: KD Hem-Fir cripple, KD Hem-Fir header

Estimated wall framing nails: ~250 total. Purchased 2026-02-20: 16d bright common shared pool with §8 and §14 (see §8 note). ✓

---

## 10. Wall Sheathing — 7/16" Zip Panel OSB

24 sheets of 7/16" Zip System panels (per receipts.csv — substituted for plain OSB), nailed per structural diaphragm schedule (Seismic D, 110 mph wind zone).

- 8d HDG common nail (2.5" × 0.131") — **substituting 3" × 0.131" HDG ring-shank**
  - Qty (panel edges): 6" o.c., all edges including intermediate studs at panel edges
  - Qty (field): 12" o.c. into studs
  - Total: ~15 sheets × ~80 nails/sheet = ~1,200 nails
  - In contact with: KD Hem-Fir studs and plates (below), Zip OSB panel (above)
  - Material depth: 7/16" Zip OSB (0.44") + 2.56" into stud = 3.0" — exceeds minimum
  - HDG specified for exterior exposure. IRC Table R602.3(1) specifies 8d common (smooth shank) for structural sheathing diaphragm — ring-shank is a deviation. Ring-shank increases withdrawal resistance (positive) but is not listed in the IRC sheathing diaphragm table. Since this shed is likely unpermitted, this is an acceptable field substitution; if an inspector is involved, note the deviation.
  - Purchased 2026-02-20 (Home Depot): DeWalt 3" .131 Ring Shank HDG Framing Nails (shared pool with §6, §7, §13). ✓

---

## 11. Truss Assembly — Plywood Gussets

9 queen-post trusses, per [6-trusses.md](6-trusses.md). Built with 1/2" structural plywood gussets on both sides of each joint, glued and nailed.

### Recommended: Plywood Gussets + Adhesive

- 8d bright common nail (2.5") or #8 × 2" bright steel screw — **substituting 2" × 0.113" HDG ring-shank**
  - Qty: ~20 fasteners per gusset × ~126 gussets (9 trusses × 8 joints × 2 sides) = ~2,500 fasteners
  - In contact with: KD SPF/Hem-Fir truss members (interior, non-PT), 1/2" structural plywood gusset
  - Material depth: 1/2" gusset + 1.5" truss member = 2.0"; 2" nail gives 1.5" penetration into member (same as screw minimum). Ring-shank improves withdrawal resistance vs smooth shank.
  - Shank is 0.113" (box gauge) vs 0.131" common — acceptable here because adhesive carries primary shear; nails are clamping fasteners. HDG is overkill for interior/protected use but not harmful.
  - Plus: construction adhesive (PL Premium or Titebond III) full coverage under each gusset. Critical — adhesive carries most of the shear.
  - Purchased 2026-02-20 (Home Depot): Grip-Rite 2" .113 Ring Shank HDG Framing Nails, 3 × 1,000 ct = 3,000 nails. Need ~2,500. ✓

Gusset sizes per joint:
- Peak: 12" × 12" — 1 per truss, 18 total (9 trusses × 2 sides)
- Queen post tops: 10" × 8" — 2 per truss, 36 total
- Queen post bottoms: 8" × 8" — 2 per truss, 36 total
- Eave joints: 8" × 10" — 2 per truss, 36 total

### Alternative: Metal Connector Plates

- Simpson TP37 truss plate (or equivalent gang-nail plate) at each joint
  - Qty: 2 per joint × 8 joints × 9 trusses = 144 plates
  - In contact with: KD truss members (non-PT)
  - Driven with a plate press or heavy dead-blow mallet. No adhesive or separate fasteners needed; cleaner appearance. Downsides: plates are expensive (~$3–5 each = ~$500+), require accurate tooth engagement, and are harder to position than gussets without a dedicated jig. Not recommended for a one-time DIY build — plywood gussets are more forgiving and use material already on-site.

---

## 12. Truss to Top Plate — Hurricane Ties

Each truss bears on the double top plate at 2 points (north and south walls). 9 trusses × 2 bearing points = 18 ties.

Simpson H2.5A hot-dip galvanized (HDG) — interior use, no PT contact.

- 10d × 1.5" HDG joist hanger nail — **substituting Simpson SD9 × 1-1/2" Structural Connector Screw**
  - Qty: 10 per tie × 18 ties = 180 fasteners
  - In contact with: KD Hem-Fir truss bottom chord, KD Hem-Fir double top plate, HDG steel tie
  - Simpson explicitly approves SD connector screws as a nail substitute in H2.5A ties. SD9 × 1-1/2" (#9 × 1.5") meets or exceeds the load values of 10d × 1.5" nails per Simpson load tables.
  - Drive with a #2 square or Robertson bit; do not overdrive.
  - Purchased 2026-02-20 (Home Depot): Simpson SD9112 #9 × 1-1/2" SD Strong Drive Structural Connector Screws, 2 × 100 ct = 200 screws. Need 180. ✓

Allowable loads (SPF/HF): Uplift 615 lbs, Lateral 110 lbs each direction.

Plus toe-nailing as backup:

- 8d bright common nail or 16d bright common nail — truss to plate, toe-nail
  - Qty: 3× 8d or 2× 16d per bearing point × 18 bearing points
  - In contact with: KD Hem-Fir truss, KD Hem-Fir top plate (non-PT)
  - In addition to hurricane ties; bright is fine — no PT contact

---

## 13. Roof Sheathing — 7/16" Zip System Panel to Trusses

~10 sheets of 7/16" Zip System panels (from the same 24-sheet purchase as wall sheathing), taped and rolled per Zip System instructions. Integrated WRB eliminates need for separate roof underlayment beneath metal roofing.

- 8d HDG common nail (2.5" × 0.131") — **substituting 3" × 0.131" HDG ring-shank**
  - Qty: ~70 per sheet × 10 sheets = ~700 nails
  - In contact with: KD Hem-Fir truss top chords (below), Zip panel (above)
  - Material depth: 7/16" Zip (0.44") + 2.56" into truss top chord = 3.0" — exceeds minimum
  - Panel edges at 6" o.c. along trusses; field at 12" o.c. HDG specified for exterior/roof exposure. Ring-shank substitution same note as §10.
  - Purchased 2026-02-20 (Home Depot): DeWalt 3" .131 Ring Shank HDG Framing Nails (shared pool with §6, §7, §10). ✓

---

## 14. Lookouts & Fly Rafters (Gable Overhang)

Ladder framing at each gable end, per [6-trusses.md](6-trusses.md).

- 16d bright common nail (3.5" × 0.162") — lookout to truss, end-nail
  - Qty: 3 per lookout end × 16 lookouts × 2 ends = 96 nails
  - In contact with: KD Hem-Fir lookout, KD Hem-Fir truss top chord
  - Material depth: lookout face 1.5" + 2.0" into truss chord = 3.5" — correct
  - Interior/protected framing; plain steel is fine — no PT contact

- 16d bright common nail — fly rafter to lookouts, face-nail
  - Qty: 2 per lookout × 16 connections = 32 nails
  - In contact with: KD Hem-Fir fly rafter, KD Hem-Fir lookout
  - Material depth: fly rafter 1.5" + 2.0" into lookout = 3.5" — correct
  - Plain steel is fine — no PT contact

Purchased 2026-02-20: 16d bright common shared pool with §8 and §9 (see §8 note). ✓

---

## 15. Metal Roofing

Fastener details TBD — depends on profile selected (standing seam vs exposed fastener).

- #10 × 1-1/2" hex washer head self-tapping screw with EPDM washer (exposed fastener profile)
  - In contact with: metal roofing panel (galvanized or Galvalume steel), CDX/OSB sheathing
  - Do not overdrive — EPDM washer seals the penetration. Material: must be compatible with roofing panel coating; manufacturer specifies fastener type.

- Hidden clip (standing seam profile)
  - In contact with: metal roofing panel, CDX/OSB sheathing
  - Clips screwed to sheathing; panels snap into clips. Fastener for clip itself is typically a #10 self-tapping or wood screw per manufacturer spec.

---

## 16. Siding — HardiePlank to Furring Strips

Per [5-wall-layers.md](5-wall-layers.md). Blind-nailed through furring + Zip OSB into studs.

- 3" SS ring-shank siding nail
  - Qty: 1 per stud per course at 16" o.c., 1" from top of plank; ~1,500 total
  - In contact with: fiber cement HardiePlank panel, 1×3 PT furring strip, Zip OSB sheathing, KD Hem-Fir stud
  - Material depth: HardiePlank ~5/16" (0.31") + 1×3 furring 3/4" (0.75") + 7/16" Zip OSB (0.44") = 1.50" before stud; 3.0" nail gives 1.50" into stud — meets Hardie's minimum 1-1/4" stud penetration spec
  - SS required — fiber cement is alkaline and will corrode plain steel or HDG nails over time. James Hardie specifies SS or hot-dip galvanized; SS ring-shank preferred for longevity.

- #8 (or #9) × 3" PT-rated screw — **acceptable length range 2½"–3½"**
  - Qty: ~50 strips × 7 screws (16" o.c. vertically over 8') = ~350; buy 500 to cover gable furring and waste
  - In contact with: 1×3 PT furring strip, Zip OSB sheathing, KD Hem-Fir stud
  - Material depth: 1×3 furring 3/4" (0.75") + 7/16" Zip OSB (0.44") = 1.19" before stud. 2.5" screw gives 1.31" into stud (minimum acceptable); 3.0" gives 1.81" (preferred); 3.5" gives 2.31" (max reasonable — field only, not at corners/door jambs where stud edges are close).
  - Coating: must be rated for ACQ/PT contact — 305 SS, or a coated structural/deck screw with a PT rating (GRK, Spax, Deckmate). Plain steel and EG corrode out. Unlike the §16 siding nails these never contact fiber cement, so SS is not strictly required.
  - Screws rather than nails: the connection is loaded in withdrawal (wind suction on the standoff siding plane), and strips must be removable for flatness correction during install.
  - Minimum #8 shank — trim-head screws lack the head bearing to hold 3/4" PT under suction.

---

## 17. Rainscreen & Housewrap

- Tyvek cap staple or cap nail
  - In contact with: Zip OSB sheathing panel face, Tyvek housewrap
  - Per manufacturer — every 12–18" along studs. Galvanized cap staples acceptable for this application (not a structural connection).

- Small SS screw or stainless staple — Cor-A-Vent bug screen at bottom of rainscreen gap
  - In contact with: Zip OSB or bottom plate, mesh bug screen
  - SS preferred for exterior exposure at sill level.

---

## Notes

- PT compatibility: All fasteners touching pressure-treated wood must be SS or HDG. ACQ treatment corrodes plain steel and electro-galvanized (EG) coatings. This applies to: pier hardware, beam screws/bolts, joist ties, rim joist nails, bottom plate nails, subfloor nails, blocking nails, and furring screws.
- Interior framing exception: Wall studs, top plates, headers, and trusses are standard (non-PT) KD lumber protected from weather. Bright (plain steel) nails are acceptable for these connections.
- Simpson fastener rules: Always use the fastener type and size specified by Simpson for their connectors. Never substitute screws for nails in hurricane ties or joist hangers unless using Simpson SD connector screws.
- Nail sizes: 16d common = 3.5", 10d common = 3", 8d common = 2.5". "Common" has a thicker shank than "box" or "sinker" — use common for structural connections.
- Zip System note: The 24 sheets of Zip System panels from receipts.csv replace the plain OSB originally specified in §10. Zip panels are nailed the same way; the integrated water-resistive barrier means housewrap behind the siding is optional (though Tyvek was also purchased — use it at the sill and jamb flashings at minimum).

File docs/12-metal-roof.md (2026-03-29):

# 12 — Metal Roof

## Panel Selection

| Parameter | Value |
|---|---|
| **Product** | Fabral Shelterguard 29ga exposed-fastener |
| **Color** | Cocoa Brown (Home Depot SKU 258948) |
| **Panel size** | 8' long x 37.75" actual (36" coverage) |
| **Source** | Home Depot |
| **Roof pitch** | 6/12 |
| **Min pitch** | 2.5/12 (per Shelterguard spec) |

---

## Roof Geometry

| Dimension | Value |
|---|---|
| Shed length (E-W) | 192" (16') |
| Overall width w/ gable overhangs | 216" (18') |
| Rafter slope length (eave to ridge) | 80.5" |
| Eave overhang | 12" |
| Panel overhang past eave | 1" (per install guide) |
| **Total panel length needed** | 80.5 + 12 + 1 = 93.5" |
| Panel length (as purchased) | 96" (8') |
| **Trim per panel** | ~2.5" off ridge end |
| Slopes | 2 (peaked gable roof) |

---

## Panel Layout

Each slope is 216" wide. Each panel covers 36".

- Panels per slope: 216 ÷ 36 = **6 panels**
- Total panels: 6 × 2 = **12 panels**
- Panels run eave-to-ridge (vertically up the slope)
- Start at one gable end, work across; first panel edge set ½" in from gable edge

---

## Underlayer Stack (already installed)

Bottom to top:
1. 7/16" Zip System sheathing (on truss top chords)
2. 2" polyiso rigid foam (R-13.1), seams taped
3. 1.5" thick wood purlins (2×4 on flat), 24" o.c., long-screwed through foam into rafters

Metal panels fasten directly to purlins with #10-16 × 1" metal-to-wood sealing screws (brown painted head, Ruspert coated, bonded EPDM washer). Source: Tacoma Screw, Kirkland branch.

---

## Trim & Flashing

All trim is produced in 10'6" sections. Allow 6" overlap where pieces join.

| Condition | Lineal ft | Pieces needed | Part |
|---|---|---|---|
| **Eave** | 18' × 2 = 36' | 4 | CE-1 Eave Trim, Cocoa Brown (SKU 175589) |
| **Ridge** (vented) | 18' | 2 | AR-3 Ridge Vent, Cocoa Brown (SKU 267588) |
| **Gable** | ~8' × 4 edges = 32' | 4 | AC1 Gable Trim, Cocoa Brown (SKU 818497) |

Notes:
- Eave trim installs *before* panels — screw to eave blocking/purlins with #9 × 1" Woodfast (no underlayment in this assembly)
- Gable trim installs *with* first/last panel on each slope
- Ridge vent installs *after* all panels and gable trim on both slopes
- Vented ridge allows airflow under metal panels above polyiso

---

## Fasteners

### Panel screws

Purlins are 24" o.c. → 2.5 screws per lineal foot of roofing (per Shelterguard table).

- 12 panels × 8' = 96 lineal ft
- 96 × 2.5 = 240 screws
- **Order: 3 pkgs (300 pcs) #10-16 × 1" sealing screws, brown**

Fastener pattern per spec:
- Eave/endlap rows: every rib (both sides of main rib)
- Intermediate purlin rows: every other rib

### Trim screws — 1" (eave & gable)

| Condition | Formula | Count |
|---|---|---|
| Eave | 36' × 1/ft | 36 |
| Gable | 32' × 2/ft | 64 |
| **Subtotal** | | 100 |

**Order: 1 pkg (100 pcs) #10-16 × 1" sealing screws, brown** (combined with panel screws = 4 pkgs total)

### Trim screws — 2" (ridge cap)

| Condition | Formula | Count |
|---|---|---|
| Ridge | 18' × 2.67/ft | 48 |

**Order: 1 pkg (100 pcs) #10-16 × 2" sealing screws, brown**

---

## Closures

| Type | Formula | Qty |
|---|---|-----|
| **Insect screen** (eave) | 36' | From existing 4" roll (shared with rainscreen) |
| **Profile vent** (vented ridge) | 18' | See sourcing notes below |

### Ridge Closure / Profile Vent — Sourcing Notes

The ridge needs something between the panel ribs and the AR-3 ridge cap to block
wind-driven rain while allowing airflow. Options, in order of preference:

1. **Fabral Shelterguard profile vent** (best fit)
   - Pre-molded foam that exactly matches the Shelterguard rib pattern
   - Look for: "Shelterguard profile vent" or product code "GR3/AT"
   - Sold in 100' rolls (you only need 18' — lots of surplus)
   - Ask at the HD roofing desk or check the Fabral accessories display near the panels
   - If not stocked, Fabral can ship from Salem OR plant: (800)477-9124

2. **Universal foam ridge vent closure** (good substitute)
   - Sold as generic strips, not profile-matched — comes in various rib heights
   - Look for: strips ~1" tall with a porous/perforated foam texture
   - You'd press/trim it to approximate the rib shape with a utility knife
   - Check that the foam is UV-stable (usually polyethylene, not polyurethane)
   - Brands: Quarrix, Air Vent, or HD house brand

3. **AR-3 with RX10 Versavent pre-attached** (alternative ridge cap)
   - Some Fabral distributors sell the AR-3 cap with the vent foam already bonded on
   - This eliminates the separate profile vent purchase entirely
   - Would replace both the AR-3 cap and the profile vent on the shopping list

**How to decide in-store**: If you see foam strips near the Shelterguard panels that have
a corrugated shape matching the panel ribs — that's option 1, buy it. If not, grab a
universal foam closure strip (option 2) and test-fit it against a panel rib in the store.
If neither is available, ask about option 3 or call Fabral.

---

## Sealant

Butyl sealant tape (¼ × 3/16 × 40' rolls):

| Condition | Formula | Feet |
|---|---|---|
| Eave | 36' × 2.1 | 75.6' |
| Gable | 32' × 1.0 | 32' |
| **Total** | | 107.6' |

107.6 ÷ 40 = 2.7 → **3 rolls**

Note: vented ridge uses profile vent instead of sealant tape.

---

## Shopping List Summary

| Item | Qty | Notes |
|---|-----|---|
| Shelterguard 29ga panels, 8', Cocoa Brown | 12 | Trim to 93.5" on site (SKU 258948) |
| CE-1 Eave Trim 10'6", Cocoa Brown | 4 | 36' of eave (SKU 175589, HD Bellevue) |
| AR-3 Ridge Vent 10'6", Cocoa Brown | 2 | 18' vented ridge (SKU 267588) |
| AC1 Gable Trim 10'6", Cocoa Brown | 4 | 32' of gable edge (SKU 818497) |
| #10-16 × 1" sealing screws, brown (100/pkg) | 4 pkgs | Panels + trim (Tacoma Screw, Kirkland) |
| #10-16 × 2" sealing screws, brown (100/pkg) | 1 pkg | Ridge vent through high ribs (Tacoma Screw, Kirkland) |
| Insect screen (4" roll) | — | Already on hand (shared with rainscreen) |
| Profile vent / ridge closure | 18' needed | See "Ridge Closure Sourcing Notes" in Closures section |
| Butyl sealant tape (40' rolls) | 3 | Eave + gable only |
| Touch-up paint (1 oz) | 1 | Cocoa Brown |
| **Gutters** | | |
| White aluminum gutter (10') | 4 | 2 per eave side (36' total, cut to fit) |
| Gutter end caps | 4 | 2 per eave |
| Gutter corners/joiners | 2 | 1 splice per eave |
| Downspouts + elbows | 4 sets | 1 per gutter end (4 corners) |
| Downspout extensions | 4 | 4'+ from piers |
| Gutter hangers/brackets | ~18 | Every 2' across 36' |

---

## Gutters

| Parameter | Value |
|---|---|
| **Type** | White aluminum K-style |
| **Source** | Home Depot (non-seamless, 10' sections) |
| **Layout** | Both eaves (N and S), 18' each |
| **Downspouts** | 4 total, one at each corner |
| **Extensions** | 4'+ from piers to direct water away from foundation |

---

## Installation Sequence

1. Install CE-1 eave trim on both eaves (screw to eave blocking with #10-16 × 1" sealing screws)
2. Staple 4" insect screen across eave gap (allows airflow, blocks pests)
3. Start first panel at one gable end, ½" in from edge, 1" overhang past eave
4. Secure with #10-16 × 1" sealing screws into purlins per fastening pattern
5. Install gable trim on first panel edge with butyl tape
6. Continue panels across, overlapping 1.75" (overlap edge over underlap edge)
7. Install gable trim on last panel edge
8. Repeat for second slope
9. Mark ridge cap edge on both sides of peak; press profile vent into place ~1" upslope of mark
10. Install AR-3 ridge vent with #10-16 × 2" screws into each panel rib, 1" back from profile vent edge

---

## References

- [Shelterguard Installation Guide](../metal-roofing-specs.pdf)
- [Purlin layout](roof-purlin-layout.svg)
- [Purlin framing details](A3-purlin-proposal.md)
- [Roof assembly & insulation](7-roof.md)

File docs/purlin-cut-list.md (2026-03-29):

# Purlin Cut List (Both Slopes)

Layout is symmetric — each roof slope is identical, quantities below are for **both slopes combined**.

## 2×4 Purlins

### Horizontal Purlins (gable overhang) — 54" each
| Qty | Length | From | Notes |
|-----|---|---|---|
| 16  | 54" | 8' 2×4 | 1 per board; 42" offcut usable for short verticals |

### Main Vertical Purlins (eave overhang) — 92.5" each
| Qty | Length | From | Notes |
|-----|---|---|---|
| 10  | 92.5"  | 8' 2×4 | 1 per board; 3.5" offcut (waste) |

### Short Vertical Purlins (gable eave corners) — 24.75" each
| Qty | Length | From | Notes |
|-----|---|---|---|
| 8 | 24.75" | offcuts | Cut from 42" horizontal purlin offcuts (1 per offcut, 8 offcuts available) |

### 2×4 Shopping Summary
| Item | Qty |
|---|-----|
| 2×4 × 8' | **26** (16 horizontal + 10 vertical) |

No additional boards needed for short verticals — they come from offcuts.

---

## 2×2 Blocking

### Vertical Gable Edge Blocking (between horizontal purlins)
| Qty | Length  | Location |
|-----|---|---|
| 4 | 25.25"  | Bottom horizontal to eave blocking |
| 4 | 18.75"  | Ridge to 1st horizontal |
| 4 | 20.5" | 1st to 2nd horizontal |
| 4 | 12.5" | 2nd to 3rd horizontal |

### Horizontal Eave Blocking (between vertical purlins at eave tip)
| Qty | Length  | Location |
|-----|---|---|
| 8 | 20.5" | T2–T3 and T7–T8 gaps |
| 8 | 19.75"  | T1–T2 and T8–T9 gaps |
| 8 | 11" | Gable edge–T1 and T9–gable edge |

### 2×2 Cut Optimization (from 8' / 96" boards)

| Board | Cuts | Used | Waste  |
|---|---|---|---|
| 1 | 25.25 + 25.25 + 25.25 + 18.75 | 94.5"  | 1.5" |
| 2 | 25.25 + 20.5 + 20.5 + 20.5 | 86.75" | 9.25"  |
| 3 | 20.5 + 20.5 + 20.5 + 20.5 | 82" | 14" |
| 4 | 20.5 + 20.5 + 19.75 + 19.75 | 80.5"  | 15.5"  |
| 5 | 19.75 + 19.75 + 19.75 + 19.75 | 79" | 17" |
| 6 | 18.75 + 18.75 + 18.75 + 12.5  | 68.75" | 27.25" |
| 7 | 12.5 + 12.5 + 12.5 + 11 + 11 + 11 + 11 | 81.5" | 14.5" |
| 8 | 11 + 11 + 11 + 11 | 44" | 52" |

### 2×2 Shopping Summary
| Item | Qty |
|---|-----|
| 2×2 × 8' | **8** |

---

## Combined Shopping List

| Item | Qty  | Notes |
|---|---|---|
| 2×4 × 8' | 26 | Purlins (all three types) |
| 2×2 × 8' | 8 | Blocking (gable edges + eave corners) |

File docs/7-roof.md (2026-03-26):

# 7 — Roof

## Configuration

| Parameter | Value |
|---|---|
| **Pitch** | 6/12 |
| **Eave overhang (N/S)** | None (rafters flush with wall face) |
| **Gable overhang (E/W)** | 1' (ladder framing) |
| **Insulation** | At roof plane (unvented/hot roof assembly) |

---

## Roof Sheathing — Zip System Envelope

Wall and roof sheathing form a continuous Zip System envelope:

- **Material**: 7/16" Zip System sheathing (wall + roof)
- **Wall panels**: 4×8 sheets cover 1.75" below subfloor + 87.25" wall frame + 7" truss end = 96" exactly
- **Roof panels**: 7/16" Zip on top of rafters, from eave (wall face) to ridge
- **Seams**: Zip System tape + roller at all panel joints
- **Nail schedule**: 6" o.c. edges, 12" o.c. field

### Layers Above Zip

Above-deck assembly (see [A2-eaves-proposal.md](A2-eaves-proposal.md) for full details):
- [x] **2" polyiso rigid foam** (R-13.1) — continuous over Zip deck, seams taped
- [ ] 2x4 purlins (flat), 24" o.c., long-screwed through foam into rafters
- [ ] Metal roofing (profile TBD — standing seam or exposed fastener)

---

## Roofing Material

*TBD — metal roof type not yet selected.*

- [ ] **Profile?** Standing seam vs. exposed fastener
- [ ] **Color?**
- [ ] **Gutters?** Recommend aluminum gutters with downspout extensions 4'+ from piers

### Standing Seam vs. Exposed Fastener
| | Standing Seam | Exposed Fastener |
|---|---|---|
| **Fasteners** | Hidden, never need re-driving | Exposed, rubber washers degrade over 20-25 yr |
| **Longevity** | 50+ years with no maintenance | May need re-fastening at 25 years |
| **Cost** | Higher | Lower |
| **DIY** | Harder (requires seaming tool or pro) | Easier |

For a 50-year building, standing seam is the better fit.

---

## Insulation (Hot Roof)

Insulation goes at the roof plane — no attic ventilation (unvented assembly).

### Exterior Rigid Foam (Above Deck)
- **2" polyiso** (R-13.1) continuous over Zip roof sheathing
- Single layer, seams taped with foil tape
- Required for IRC R806.5 compliance: exterior insulation must be ≥40% of total roof R-value in zone 4C unvented assemblies. At R-13.1 / (R-13.1 + R-15) = **47%** — compliant.

### Cavity Insulation (Between Rafters)
- Rockwool ComfortBatt R-15 friction-fit between truss top chords (3.5" cavity)
- Hold in place with insulation support wire (zig-zag wire stapled between rafters)

**Total roof R-value: ~R-28** (R-13.1 exterior + R-15 cavity)

### Interior Finish
- 1/2" CDX plywood over Rockwool (can be painted)
- No dedicated vapor barrier needed for zone 4C — latex paint is a Class III retarder and code-compliant
- For additional insurance on a hot roof: CertainTeed MemBrain smart vapor retarder (~$50-70) stapled under rafters before plywood

### Moisture Management Notes
With no ventilation above the insulation:
- Ensure thorough air sealing at the wall-to-roof connection
- Roof sheathing underlayment/barrier handles exterior moisture
- Mini-split or dehumidifier controls interior humidity

---

## Underlayment & Flashing

*TBD — details to be added before installation.*

- Ice & water shield at eaves (2' minimum)
- Synthetic underlayment over full roof
- Drip edge at eaves (installed before underlayment)
- Drip edge at rakes (installed over underlayment)
- Closure strips at panel ends (ridge and eave)

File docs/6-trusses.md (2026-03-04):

# 6 — Trusses (Queen-Post Design)

## Configuration

| Parameter | Value |
|---|---|
| **Type** | Queen-post (simplified — no diagonal web members) |
| **Pitch** | 6/12 (26.57°) |
| **Span** | 12' (144") between walls |
| **Rise at peak** | 36" above bottom chord |
| **Spacing** | 24" o.c. (9 trusses total) |
| **Eave overhang** | None (rafters flush with wall exterior) |
| **Lumber** | All 2×4 (1.5" × 3.5" actual) |
| **Count** | 9 trusses (at 0", 24", 48", …, 192") |

## Truss Anatomy

```
                        Peak
                         /\
                        /  \
                       /    \
            Rafter →  /      \  ← Rafter
                     /   SB   \
                    /    ══    \      SB = Straining Beam (48")
                   /     ||     \     QP = Queen Post
                  /      ||QP    \
                 /    QP ||      \
                /        ||       \
    ═══════════════════════════════════  ← Bottom Chord (144")
    ↑          ↑         ↑         ↑
  Eave    Queen Post  Queen Post  Eave
  (y=0)    (y=48")    (y=96")   (y=144")
```

## Member Dimensions and Functions

| Component | Location | Stress Type | Function |
|---|---|---|---|
| Bottom chord | Horizontal, full span (144") | Tension + bending | Ties rafter ends together, supports attic storage |
| Rafters | Angled, wall face to peak (~80.5" each) | Compression + bending | Supports roof sheathing and loads |
| Queen posts | Vertical at 46.25" and 97.75" from south | Compression | Supports rafters mid-span, transfers load to bottom chord |
| Straining beam | Horizontal between QP tops (48") | Compression | Keeps queen posts from tilting inward |

**Key dimensions (from `dimensions.scad`):**
- Queen post inset: 46.25" from each wall
- Queen post height: 23.125"
- Straining beam width: 48"
- Straining beam sits 24" above bottom chord top

## Gable End Overhang (Ladder Framing)

- **Overhang:** 1' (12") past E/W walls
- **Lookouts:** 2×4s at 24" o.c., extending from second truss to fly rafter
- **Fly rafters:** Full-length rafters at outer edge of lookouts
- Lookouts lie in roof plane (angled to match slope)

Ladder framing attaches to the second truss inboard (at x=24" for west, x=168" for east) and extends out to the fly rafter position (x=−12" for west, x=204" for east).

## Construction Method — Plywood Gussets

**Recommended for DIY construction:**
- Cut 1/2" or 3/4" structural plywood into gusset plates
- Sandwich each joint between gussets on both sides
- Glue (construction adhesive) + 8d nails or #8 screws at 3" o.c.
- Build trusses flat on shed floor deck (use as assembly jig)

**Typical gusset sizes:**
| Joint | Minimum Size |
|---|---|
| Peak | 12" × 12" |
| Queen post tops | 10" × 8" |
| Queen post bottoms | 8" × 8" |
| Eave joints | 8" × 10" |

## Load Analysis

### Design Loads (City of Redmond)

| Load Type | Value | Notes |
|---|---|---|
| Dead load (roofing) | 10 psf | Metal roofing + sheathing |
| Ground snow load | 15 psf | Per ASCE 7-10 |
| Rain-on-snow surcharge | 5 psf | Per ASCE 7-10 7.10 |
| **Total roof load** | **30 psf** | Conservative design value |

### Per-Truss Loading (at 24" o.c.)

```
Tributary width: 2'
Roof area per truss: 2' × 12' = 24 sf
Total load per truss: 24 sf × 30 psf = 720 lbs
Load per rafter: 360 lbs (split between two sides)
```

### Rafter Check (2×4 SPF #2 — conservative)

Queen posts at 1/3 points break each rafter into supported segments:
- Wall to queen post: 48" (4') — **governs**
- Queen post to peak: 24" (2')
- No eave overhang (rafters terminate at wall face)

```
Fb = 875 psi, S = 3.06 in³ (SPF #2 — lower Fc/Ft than Hem-Fir, similar Fb)
Distributed load: 360 lbs over 6' = 60 plf

Max moment (48" span): M = wL²/8 = 60 × 4² / 8 = 120 ft-lbs = 1,440 in-lbs
Allowable moment: Mr = Fb × S = 875 × 3.06 = 2,678 in-lbs
Utilization: 1,440 / 2,678 = 54% ✓ OK

Axial compression: braced by roof sheathing (no buckling reduction needed)
Combined bending + compression: both well under capacity — interaction passes
```

**2×4 rafters are adequate.** Full structural analysis in `shed/truss.js`.

## Attic Storage Capacity

The queen-post design creates usable storage voids on each side of the straining beam.

### Bottom Chord Storage Loading

```
Queen posts divide bottom chord into three ~4' segments
2×4 SPF/Hem-Fir properties:
  - Section modulus: S = 3.06 in³
  - Allowable bending: Fb = 875 psi (with Cr factor)
  - Allowable moment: M = 875 × 3.06 = 2,678 in-lb = 223 ft-lb

For 4' span with uniform load:
  w = 8M / L² = 8 × 223 / 16 = 111 plf

At 24" truss spacing:
  Storage capacity = 111 plf / 2' = 55 psf per bay
```

### Storage Capacity Summary

| Location | Span | Capacity | Notes |
|---|---|---|---|
| Between queen posts | 4' | 55 psf | Light storage (boxes, seasonal items) |
| Center bay | 4' | 55 psf | Same — straining beam doesn't support floor |

**55 psf** is adequate for boxes of holiday decorations, light furniture, and seasonal gear.

**To increase capacity:**
- Sister additional 2×4 to bottom chord (doubles capacity)
- Add plywood flooring across bottom chords (distributes point loads)
- Keep heavy items near queen posts (shorter effective span)

## Materials Summary

| Component | Size | Quantity | Material |
|---|---|---|---|
| Trusses | 2×4 members | 9 | SPF or Hem-Fir #2 |
| Gusset plates | 1/2" plywood | ~2 sheets | Structural plywood |
| Lookouts | 2×4 × 36" | 16 | SPF (8 per gable end) |
| Fly rafters | 2×4 × 14' | 2 | SPF |
| Roof sheathing | 7/16" × 4×8 | ~10 sheets | Zip System (taped + rolled) |
| Metal roofing | (TBD) | ~200 sf | Standing seam or corrugated |
| Fascia | 1×6 or 1×8 | 32 lf | Cedar or primed pine |
| Barge boards | 1×6 or 1×8 | 32 lf | Cedar or primed pine |

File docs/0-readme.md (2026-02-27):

# Shed Design

## Design Notes (Hem-Fir #2)
- **Lumber**: Hem-Fir #2 PT (Fb=850 psi, E=1,300,000 psi)
- **Storage load**: 60 psf (70 psf total with 10 psf dead load)

## Fundamental Goals

16 x 12 shed built with a joist-over-beam floor resting on six concrete piers.
East and center piers rise to beam level (beam sits directly on concrete via saddle hardware); only the two west piers are short and use 6×6 posts to reach the beam.
Posts are inset ~1' from the shed edges to protect the underfloor structure from rain.
The shed should have a steeper roof (possibly metal) to help shed pine needles.
The floor should support 60psf storage loads.

Model in C:\Users\adamt\OneDrive\Documents\OpenSCAD\shed_model.scad 

## City of Redmond Design Requirements 
Design Wind Speed: 110 mph - PER IRC 301.2 (see  Table IBC 1609.3 for commercial) 
Ground Snow Load: 15 psf (snow drift per ASCE 7-10) 
Rain on Snow Surcharge: 5 psf added to flat roofs per (ASCE 7-10;7.10) 
Seismic Design Category: D (D2 Residential) 
Rainfall : 1”/hr (UPC Table D101.1) 
Frost Line Depth: 12” 
Soil Bearing Capacity: 1500 psf unless a Geotechnical report is provided (IBC Table 1806.2) 

## Structural Design

### Site Orientation and Ground Slope

**Orientation:** The 16' dimension runs East-West. The 12' dimension runs North-South.

**Ground Slope:** The site slopes 28" over the 16' E-W length:
- **East end:** High ground (reference elevation 0")
- **West end:** Low ground (28" below east)

This slope affects post heights - see Vertical Posts section.

---

### Footing Layout (Inset Design)

To protect the underfloor structure from rain, footings are inset ~1.5' from N/S edges:

```
                    16' (shed footprint)
    EAST          ←─────────────────────────→          WEST
  (high ground)                                    (low ground)
                  ┌─────────────────────────┐ ─┬
                  │  1'      7'        7' 1'│  │
     Beam 1 (N):  │  ●───────●─────────●    │  │ 12'
                  │          FLOOR          │  │
     Beam 2 (S):  │  ●───────●─────────●    │  │
                  │  ↑       ↑         ↑    │ ─┴
                  └─────────────────────────┘
                    1'      8'        15'  (from east edge)

      Beams @ 1.5' and 10.5' from north edge (front)
```

**Key Dimensions:**
- **Joist main span:** 9' (between beams)
- **Joist cantilever:** 1.5' on each end (supports walls)
- **Beam spans:** 7' + 7' (between posts)
- **Beam cantilever:** 1' on each end

---

### Load Summary

**Floor Design Load:**
- Dead Load (structure): 10 psf
- Live Load (storage): 60 psf
- **Total: 70 psf**

**Wall Line Load (at joist cantilever tips):**
- Wall dead load: 8' × 7 psf = 56 plf
- Roof load (tributary): ~6' × 30 psf = 180 plf
- **Total: 236 plf → 315 lbs per joist at 16" o.c.**

**Total Building Weight (estimated):**
| Component | Calculation | Weight |
|---|---|---|
| Floor DL | 192 sf × 10 psf | 1,920 lbs |
| Storage LL | 192 sf × 60 psf | 11,520 lbs |
| Walls | 56 lf × 8' × 7 psf | 3,136 lbs |
| Roof DL | 200 sf × 10 psf | 2,000 lbs |
| Snow LL | 192 sf × 20 psf | 3,840 lbs |
| **Total** | | **22,416 lbs** |

---

### Concrete Piers (Poured)

Six piers on BigFoot form feet — **poured and cured.** See [`1-piers.md`](1-piers.md) for full design, sizing, and as-built measurements.

```
Post positions: 1', 8', 15' on each beam

Beam 1:  [P1]────────[P2]────────[P3]    P1, P3 = corner (BF24 + 10" tube)
          │           │           │       P2 = center (BF28 + 12" tube)
         ═══════════════════════════     (both beams identical)
          │           │           │
Beam 2:  [P4]────────[P5]────────[P6]
```

| Position | Load | BigFoot | Bearing | Status |
|---|---|---|---|---|
| Corner (×4) | ~2,580 lbs | BF24 (25.5" base) | 914 psf / 1,500 | **Pass (61%)** |
| Center (×2) | ~6,220 lbs | BF28 (29.5" base) | 1,478 psf / 1,500 | **Pass (99%)** |

East and center piers rise to beam level (beam on concrete via saddle hardware). Only the two west piers are short and use 6×6 posts. Total concrete: 26.1 cf (58 × 60-lb bags). Each pier has one #4 GFRP rebar. See [`1-piers.md`](1-piers.md) for as-built measurements.

---

### Vertical Posts and Beam Supports

**As-Built Configuration:**

The east and center piers rise to beam level — the beam sits directly on concrete via saddle hardware at these 4 positions (no wood posts). Only the 2 west piers are short and require 6×6 posts to bridge the gap to the beam.

| Position | Location | Connection Type | Notes |
|---|---|---|---|
| 1' from east | **East end** | **Beam direct to concrete** | Tall pier; ABU66SS as beam saddle |
| 8' from east | **Center** | **Beam direct to concrete** | Tall pier; ABU66SS as beam saddle |
| 15' from east | **West end** | **6×6 post on short pier** | ABU66SS base + CC66 post cap |

**Post Material (west positions only):** 6×6 pressure-treated Hem-Fir #2 (or better). As-built post heights (wood only, excluding metal brackets): south 16.5", north 17.25".

**Column Capacity Check:**
- 6×6 actual dimensions: 5.5" × 5.5"
- Allowable load for 6×6 Hem-Fir #2 at short heights: **>10,000 lbs** (far exceeds ~2,580 lbs required)

**Hardware Connections:**

All hardware uses post-install anchors (wedge anchors or similar), allowing concrete piers to be poured first.

| Position | Base Hardware | Top Hardware | Notes |
|---|---|---|---|
| **East (1')** | Simpson ABU66SS | — | Beam sits in ABU66SS used as saddle |
| **Center (8')** | Simpson ABU66SS | — | Beam sits in ABU66SS used as saddle |
| **West (15')** | Simpson ABU66SS | Simpson CC66 | 6×6 post in base; beam on post cap |

*All 6 positions use ABU66SS (stainless, 5.5" pocket fits the built-up beam width). West positions add CC66 post caps (1 per post). See [`2-beam.md`](2-beam.md) for hardware links and pricing.*

**Anchor Requirements:**
- **½" diameter post-install wedge anchor** (Simpson Titen HD, Red Head, or equivalent)
- Minimum 7" embedment in concrete
- All bases provide 1" standoff above concrete for drainage/moisture protection

---

### Horizontal Beams (2 beams × 16 ft each)

**Configuration (with inset posts):**
- Posts at: 1', 8', 15' along each 16' beam
- Interior spans: 7' + 7'
- End cantilevers: 1' on each end

```
    ←1'→←───── 7' ─────→←───── 7' ─────→←1'→
    ▓▓▓▓▓▓▓▓▓▓▓▓▓▓▓▓▓▓▓▓▓▓▓▓▓▓▓▓▓▓▓▓▓▓▓▓▓▓▓▓  ← beam with joist loads
        △              △              △
      Post 1         Post 2         Post 3
```

**Beam:** 2×10 + 3×10 + 2×10 built-up (5.5" × 9.25"), Hem-Fir #2 PT Incised. Connected with 1/2" × 6-1/2" HDG hex bolts + nuts + washers, staggered top/bottom at 24" o.c., 8 per beam.

**Utilization:** 89% bending, 77% shear, 15% deflection — all pass. Run `node shed/beam.js` for full analysis. See [`2-beam.md`](2-beam.md) for design notes, NDS adjustment factors, and solid 6×10 comparison.

---

### Floor Joists, Blocking, and Decking

**2×8 PT Hem-Fir #2 Incised** at 16" o.c. — 13 joists running N-S (12' total: 1.5' cantilever + 9' span + 1.5' cantilever). Cantilevers support exterior wall loads. Includes 24 blocks at beam lines for lateral load transfer and 3/4" plywood decking.

**Structural:** 56% bending, 57% deflection — passes with comfortable margin. Run `node shed/joist.js` for full analysis. See [`3-joists.md`](3-joists.md) for complete design, NDS factors (including incising and repetitive member derating), cut list, and nailing schedule.

**Lateral Load Path:** Plywood diaphragm → blocking → beams → posts/saddles → piers → anchors. With pinned post bases (ABU hardware), the floor diaphragm is the primary lateral system.

**Hurricane Ties:** Simpson H2.5ASS (26 total — joist-over-beam uplift restraint) | **Decking:** 3/4" T&G Advantech or CDX plywood (6 sheets)

---

### Wall Framing

2×6 studs at 16" o.c. with PT bottom plate and double top plate. One door opening (~33" R.O.) with (2) 2×6 header on north wall. See [`4-walls.md`](4-walls.md) for stud layout and door framing, [`5-wall-layers.md`](5-wall-layers.md) for the full exterior assembly: R-23 Rockwool → 7/16" OSB → Tyvek → ¾" rainscreen → HardiePlank siding (6.25" exposure).

---

### Materials Summary (6-Position Inset Design)

**Concrete & Foundation:**
| Component | Size | Quantity | Material |
|---|---|---|---|
| BigFoot form feet (corner) | 25.5" base | 4 | Polypropylene |
| BigFoot form feet (center) | 29.5" base | 2 | Polypropylene |
| Sonotubes (corner) | 10" dia × 48" | 4 | Cardboard form (cut to length) |
| Sonotubes (center) | 12" dia × 48" | 2 | Cardboard form (cut to length) |
| GFRP rebar | #4 × ~2' | 6 | Fiberglass |
| Concrete | 4000 psi | 26.1 cf (58 bags used @ 60-lb) | Ready-mix or bags |

**Hardware (post-install anchor compatible):**
| Component | Part Number | Quantity | Notes |
|---|---|---|---|
| Base brackets (all positions) | Simpson ABU66SS | 6 | Stainless, 5.5" pocket; beam saddle at E/C, post base at W |
| Post caps (west only) | Simpson CC66 | 2 | Painted, 1 per post (beam-to-post) |
| Wedge anchors | ½" × 7" | 6 | Post-install, for all bases |
| Hurricane ties | Simpson H2.5ASS | 26 | Joist-to-beam uplift restraint (stainless) |
| Framing angles (optional) | Simpson A35 | 48 | For blocking (2 per block) |

**Lumber:**
| Component | Size | Quantity | Material |
|---|---|---|---|
| Posts (west only) | 6×6 × TBD | 2 | PT Hem-Fir #2 (measure on-site after pier cure) |
| Beams | 2×10 × 16' | 4 | PT Hem-Fir #2 (outer plies: 2 per beam × 2 beams) |
| Beams | 3×10 × 16' | 2 | PT Hem-Fir #2 (center ply: 1 per beam × 2 beams) |
| Joists | 2×8 × 12' | 13 | PT Hem-Fir #2 |
| Rim joists | 2×8 × 16' | 2 | PT Hem-Fir #2 |
| Blocking | 2×8 × 14.5" | 24 | PT Hem-Fir #2 (cut from 2×8 stock) |

**Sheathing:**
| Component | Size | Quantity | Material |
|---|---|---|---|
| Subfloor | 3/4" × 4×8 | 6 sheets | Advantech or CDX |

**Notes:**
- Joists run N-S (parallel to 12' dimension), cantilever 1.5' past each beam
- Beams run E-W (parallel to 16' dimension), cantilever 1' past corner posts
- All cantilevers support exterior wall loads
- East and center positions have no wood posts — beam sits directly in ABU66SS on concrete
- As-built post heights: south 16.5", north 17.25" (wood only, excluding brackets)

---

### Roof Structure

**Design Goals:**
- Steep pitch to shed pine needles
- Metal roofing for durability and low maintenance
- Usable attic storage space (queen-post truss design creates voids)

Queen-post trusses with 6/12 pitch, 2×4 lumber, 24" o.c. spacing (9 total). Eave overhang 1' past N/S walls; gable overhang 1' past E/W walls via ladder framing (lookouts + fly rafters). Rafter utilization 54%, attic storage capacity 55 psf per bay. See [`6-trusses.md`](6-trusses.md) for full truss design, load analysis, attic storage capacity, construction method (plywood gussets), and materials list.

---

## Dunn Lumber Price Reference

Source: dunnlumber.com, Framing Lumber > Dimensional Lumber. Fetched February 2026.

**Important:** These are standard **Kiln Dried (non-PT)** prices. Pressure-treated lumber (needed for posts, beams, and joists in ground-contact/outdoor applications) costs significantly more. The PT prices in the Design Notes section above remain the best estimates for underfloor components.

### Dimensional Lumber (per linear foot)

| Size | Hem-Fir | Douglas Fir | SPF |
|---|---|---|-----|
| 2×4 | **$0.58** | $0.63–0.65 | $0.78 |
| 2×6 | **$0.88** | $0.96–1.00 | $1.18 |
| 2×8 | **$1.18** | $1.19 (16' only) | $1.78 |
| 2×10 | **$1.48** | — | $1.98 |
| 2×12 | **$1.78–1.88** | $2.68 (16' only) | $3.08 |

### Pre-Cut Studs — 2×4 (per each)

| Length | Hem-Fir | Douglas Fir | SPF |
|---|---|---|-----|
| 92⅝" (8' wall) | **$4.58** | $4.70 | $5.08 |
| 96" | **$4.88** | — | $5.18 |
| 103½" (9' wall) | $5.68 | **$5.38** | — |
| 104⅝" | $5.68 | $5.77 | — |
| 120" (10' wall) | **$6.18** | — | — |

### Pre-Cut Studs — 2×6 (per each)

| Length | Hem-Fir | Douglas Fir | SPF |
|---|---|---|-----|
| 88⅝" | — | — | **$4.08** |
| 92⅝" (8' wall) | **$6.28** | $6.40 | $7.78 |
| 96" | **$6.38** | $7.48 | $7.08 |
| 103½" (9' wall) | $8.78 | **$7.98** | — |
| 104⅝" | $8.98 | **$8.88** | — |
| 120" (10' wall) | **$9.38** | $10.28 | — |

### Takeaways

- **Hem-Fir is cheapest** for most sizes — 8–34% less than Douglas Fir, 25–50% less than SPF
- **Douglas Fir** is a close second for 2×4 and 2×8, with only limited 2×12 availability (16' lengths)
- **SPF is the most expensive** across the board despite being labeled "Premium"
- For **wall studs (2×4-92⅝")**, the species spread is small: $4.58–$5.08 (only $0.50/stud)
- For **joists/beams (2×8, 2×12)**, Hem-Fir saves substantially vs. SPF ($1.18 vs $1.78 for 2×8)
- The shed design's choice of **Hem-Fir #2** is well-supported by pricing

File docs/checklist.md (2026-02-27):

# Shed Construction Checklist

*Building from the ground up - 16' x 12' shed with joist-over-beam floor on concrete piers*

Completed sections should be moved to checklist-completed.md

---

## Open Questions & Design Decisions

*Resolve these before finalizing materials and construction details. Decided items in checklist-completed.md.*

### Still Open

- [ ] **Roof profile** — standing seam vs. exposed fastener (see `docs/7-roof.md`)
- [ ] **Roof color**
- [ ] **Gutters** — aluminum recommended for pier protection; 4'+ downspout extensions (see `docs/7-roof.md`)
- [ ] **Mini-split sizing and placement** — 9k vs. 12k BTU; which walls for head and outdoor unit (see `docs/11-trades.md`)
- [ ] **Dehumidifier** — standalone unit with floor drain line for shoulder-season humidity (see `docs/11-trades.md`)
- [ ] **Floor finish** — epoxy, sealer, or bare Advantech (see `docs/9-finishings.md`)
- [ ] **Exterior lighting** — motion-activated, switched from inside, or none (see `docs/11-trades.md`)

---

## 0. Permits & Planning

- [x] ~~Check if permit required~~ - Under 200 sf, no structural permit
- [x] Confirm setback requirements (property lines, easements) - *still applies even without permit*
- [x] Verify utility locations (call 811) - *required for electrical trench if underground feed*
- [x] ~~Pull electrical permit for power feed to shed~~ - Later.

### Tools & Safety
- [x] Post-hole digger or auger
- [x] Level (4' minimum)
- [x] String line and line level <used laser level instead>
- [x] Transit or laser level (for elevation control)
- [x] Circular saw / miter saw
- [x] Drill/impact driver
- [x] Framing nailer (optional but recommended)
- [x] Safety glasses, hearing protection, gloves
- [x] First aid kit on site

---

## 3. Post Bases & Hardware

### Layout Verification
- [ ] Re-check pier positions against beam layout
- [ ] Mark anchor bolt locations on pier tops
- [ ] Verify elevations match design (east piers highest)

### Anchor Installation
- [ ] Drill 5/8" holes for Titen HD screw anchors (min 6" deep, overdrill 1/2" past embedment)
- [ ] Install Simpson ABU66SS at east positions (2) - beam direct to concrete, using 5/8" × 6" Titen HD (THDB62600H4SS)
- [ ] Install Simpson ABU66SS at center positions (2) - beam direct to concrete, using 5/8" × 6" Titen HD
- [ ] Install Simpson ABU66SS at west positions (2) - for 6×6 posts, using 5/8" × 6" Titen HD
- [ ] Torque all anchors to spec (max 85 ft-lbf)

---

## 4. Vertical Posts (West Only — 2 posts)

*East and center positions have no posts — beam sits directly on tall piers via ABU66SS saddles.*

### Cutting
- [x] Measure beam-bottom-to-pier-top gap at each west position (after pier cure)
- [ ] Cut 2 west posts: 6×6 — south 16.5", north 17.25" (as-built, wood height only)

### Installation
- [ ] Set posts in ABU66SS bases at west positions
- [ ] Check plumb on two faces
- [ ] Temporarily brace posts
- [ ] Install Simpson CC66 post caps on both west posts

---

## 5. Beams (2 × 16')

### Fabrication
- [ ] Select straight stock: 2×10 outer plies (4 pcs) + 3×10 center ply (2 pcs), all 16' PT Hem-Fir #2
- [ ] Crown all pieces same direction
- [ ] Clamp all 3 plies together, drill 1/2" holes through full 5.5" width
- [ ] Laminate with 1/2" × 6.5" HDG carriage bolt + nut + 2 washers, staggered top/bottom at 24" o.c. (8 bolts per beam); edge distance ≥ 1.5"

### Installation
- [ ] Set beams in ABU66SS saddles at east end (beam direct to concrete)
- [ ] Set beams in ABU66SS saddles at center (beam direct to concrete)
- [ ] Shim all 4 ABU66SS positions with 1/2" structural plywood each side of beam
- [ ] Set beams in CC66 post caps at west posts
- [ ] Verify beams are level east-to-west
- [ ] Verify beams are parallel (9' apart center-to-center)
- [ ] Verify 1' cantilever at each end
- [ ] Bolt post caps to beams per CC66 spec (5/8" × 8" HDG bolts)

---

## 6. Floor Joists

### Layout
- [ ] Mark joist locations on beams at 16" o.c.
- [ ] Verify 13 joists fit in 16' span (joist-over-beam framing — no hangers)

### Joist Installation
- [ ] Cut 11 field joists: 2×8 × 12'
- [ ] Set joists on top of beams, bear directly (joist-over-beam)
- [ ] Verify 1.5' cantilever past each beam on both N and S sides
- [ ] Install Simpson H2.5ASS hurricane ties at each joist-beam intersection (26 total — 13 joists × 2 beams); SS nails per Simpson schedule
- [ ] Check joists for level and adjust as needed

### Rim Joists
- [ ] Cut 2 rim joists: 2×8 × 16'
- [ ] Install at joist ends (east and west)
- [ ] Face-nail through rim into joist ends

### Blocking
- [ ] Cut 24 blocks: 2×8 × 14.5"
- [ ] Install blocking between joists at each beam line
- [ ] Toe-nail or use Simpson A35 angles
- [ ] Ensure tight fit for diaphragm shear transfer

---

## 7. Subfloor

### Sheathing
- [ ] Dry-fit 6 sheets of 3/4" plywood/Advantech
- [ ] Stagger joints - no 4-corner intersections
- [ ] Leave 1/8" gap at panel edges for expansion
- [ ] Glue with construction adhesive (optional but recommended)
- [ ] Fasten with 8d ring-shank or #8 × 2" screws
- [ ] Nail schedule: 6" o.c. at edges, 12" o.c. in field
- [ ] Set fastener heads flush (not countersunk)

### Quality Check
- [ ] Walk floor checking for squeaks
- [ ] Verify no bounce or excessive deflection
- [ ] Check perimeter is square for wall framing
- [ ] Check floor is level side-to-side and end-to-end
- [ ] Verify cantilever lengths (1.5' past each beam)

---

## 8. Wall Framing

### Bottom Plates
- [ ] Cut PT bottom plates to length
- [ ] Mark stud layout at 16" o.c.
- [ ] Mark door rough opening on north wall (east end, ~33" wide × ~78" tall)
- ~~Mark window rough openings~~ - No windows

### Stud Walls (2×6 at 16" o.c.)
- [ ] Cut studs to height (92-5/8" for 8' walls)
- [ ] Cut top plates (single, then double)
- [ ] Frame walls flat on deck
- [ ] Install cripples, headers, king studs, jack studs at openings
- [ ] Square each wall before standing

### Wall Raising
- [ ] Raise and brace first wall
- [ ] Raise remaining walls
- [ ] Nail bottom plates to subfloor/rim
- [ ] Plumb and brace corners
- [ ] Nail corners together
- [ ] Install double top plates with staggered joints
- [ ] Overlap top plates at corners (minimum 24" past joint)
- [ ] Tie top plate corners with metal straps or let-in

### Lateral Bracing (Seismic D, 110 mph wind)
- [ ] Install let-in bracing or structural sheathing on walls
- [ ] Nail sheathing per high-wind schedule if required
- [ ] Install hold-down anchors at shear wall ends if required

### Headers
- [ ] Size per span: (2) 2×6 up to 4', (2) 2×8 up to 6', (2) 2×10 up to 8'
- [ ] Install with 1/2" plywood spacer if needed for wall depth

---

## 9. Roof Structure

### Truss Components (per truss × 9)
- [ ] Cut bottom chords: 2×4 × 12' (144")
- [ ] Cut rafters: 2×4 at 6/12 pitch
- [ ] Mark and cut bird's mouth at wall bearing points
- [ ] Mark and cut plumb cuts at ridge
- [ ] Mark and cut tail cuts at overhang ends
- [ ] Cut queen posts: 2×4 × ~23" (at 46" inset from ends)
- [ ] Cut straining beams: 2×4 × 48" horizontal
- [ ] Cut gusset plates from 1/2" plywood

### Truss Assembly
- [ ] Build assembly jig on shed floor
- [ ] Cut gussets: peak (12"×12"), queen post tops (10"×8"), queen post bottoms (8"×8"), eaves (8"×10")
- [ ] Assemble trusses with construction adhesive + 8d nails at 3" o.c.
- [ ] Double-gusset all joints (both sides)
- [ ] Verify overall dimensions match jig
- [ ] Stack completed trusses flat with stickers

### Truss Installation
- [ ] Mark truss locations on top plates at 24" o.c. (9 trusses)
- [ ] Set first truss at gable end, flush with wall sheathing
- [ ] Install hurricane ties/clips at each bearing point (H2.5A or similar)
- [ ] Brace trusses with temporary lateral bracing
- [ ] Set remaining trusses
- [ ] Verify 1' eave overhang past N/S walls
- [ ] Install permanent purlins or ridge blocking as bracing

### Gable Overhangs (Ladder Framing)
- [ ] Cut lookouts: 2×4 × 36" (8 per gable end, angled to roof plane)
- [ ] Install lookouts at 24" o.c. from second truss to fly rafter
- [ ] Cut fly rafters to match main rafter profile (bird's mouth, plumb cut, tail cut)
- [ ] Install fly rafters at 1' past E/W walls

### Fascia & Barge Boards
- [ ] Install fascia along eaves (1×6 or 1×8)
- [ ] Install barge boards along gable rakes

---

## 10. Roof Sheathing

- [ ] Install 7/16" Zip System panels
- [ ] Start at eave, work up to ridge
- [ ] Stagger joints
- [ ] H-clips between panels if required
- [ ] Nail 6" o.c. edges, 12" o.c. field
- [ ] Extend to cover fascia edge (drip edge support)

---

## 11. Roofing

### Underlayment
- [ ] Install drip edge at eaves first
- [ ] Install ice & water shield at eaves (2' minimum)
- [ ] Install synthetic underlayment or felt
- [ ] Install drip edge at rakes over underlayment
- [ ] Seal all penetrations

### Metal Roofing
- [ ] Install eave trim/starter
- [ ] Install panels from eave to ridge
- [ ] Overlap panels per manufacturer spec
- [ ] Use correct fasteners (with rubber washers)
- [ ] Don't overdrive fasteners
- [ ] Install ridge cap
- [ ] Install gable trim
- [ ] Seal panel ends at ridge and eave with closure strips
- [ ] Bond metal roofing to ground rod if code requires

---

## 12. Exterior Walls

### Sheathing
- [ ] Install 7/16" Zip System panels (purchased — 14 sheets); integrated WRB replaces plain housewrap on sheathing face
- [ ] Nail per diaphragm schedule: 8d (3" ring-shank HDG) 6" o.c. edges / 12" o.c. field into studs
- [ ] Leave gap at door opening

### Weather Barrier
- [ ] Tape all Zip panel seams with Zip tape
- [ ] At door opening: apply flexible flashing tape (Vycor or similar) at sill, jambs, head (in that order)
- [ ] Integrate with roof underlayment at top
- [ ] Install Tyvek at sill and any areas not covered by Zip panels

### Rainscreen
- [ ] Install Cor-A-Vent SV-3 bug screen strip at base of each wall (¾" gap for air intake)
- [ ] Install 1×3 vertical furring strips at 16" o.c. over Zip panels, aligned with studs (#8 × 3" SS screws)
- [ ] Leave top gap open behind fascia for exhaust

### Siding (HardiePlank Cedarmill, 8.25" plank, 6.25" exposure)
- [ ] Install HardiePlank starter strip at bottom of each wall (behind first course)
- [ ] Install aluminum outside corner pieces course-by-course (4 corners, 16 courses = 64 pieces)
- [ ] Install door trim/casing (PVC or HardieTrim)
- [ ] Install HardiePlank courses from bottom up — all walls use 12' planks; N/S walls need 2 planks per course with butt joints staggered ≥24" between courses
- [ ] Blind-nail 1" from top of plank with 3" SS ring-shank siding nails, into studs (through furring + Zip OSB)
- [ ] Leave 1/8" gap at butt joints; caulk with paintable exterior sealant
- [ ] Prime and paint all cut edges immediately (exposed fiber cement absorbs water)
- [ ] Field-paint to match house

---

## 13. Door Installation

*(No windows)*

### Door
- [ ] Verify rough opening
- [ ] Install threshold/sill pan
- [ ] Set door unit
- [ ] Shim hinge side first
- [ ] Check operation
- [ ] Fasten through shims
- [ ] Install hardware
- [ ] Flash head
- [ ] Install exterior casing
- [ ] Caulk perimeter
- [ ] Weatherstrip as needed

### Flashing Details
- [ ] Flashing tape at door corners
- [ ] Metal drip cap above door

---

## 14. Electrical

### Underground Feed (DIY trench, hired electrician)
- [ ] Plan trench route from house panel to shed
- [ ] Call 811 before digging
- [ ] Dig trench (18" deep minimum for UF cable, 24" for PVC conduit)
- [ ] Install conduit in trench
- [ ] Electrician: pull wire through conduit
- [ ] Backfill and compact trench

### Shed Wiring (electrician)
- [ ] Install small sub-panel (4-space, electrician will size)
- [ ] Circuit 1: Mini-split dedicated circuit (20A or 30A per unit spec)
- [ ] Circuit 2: Lights + outlets (15A or 20A)
- [ ] Install two switches by door: one for lights, one main disconnect (kills all power)
- [ ] Install outlet(s) near door
- [ ] Install LED light fixture(s)
- [ ] Mini-split whip/disconnect on exterior wall
- [ ] Pull electrical permit
- [ ] Schedule inspection

---

## 15. Insulation & Interior Finishing

### Floor Insulation (before or after subfloor - see Section 7)
- [ ] Drop hardware cloth between joists from above; staple to joist sides or bottom edges (cloth acts as shelf for foam)
- [ ] Lower 3" polyiso boards (Rmax ThermoSheath-3 R-20.3) onto cloth — foam rests between cloth (below) and subfloor (above)
- [ ] Cut boards snug; seal edges with canned spray foam for air sealing

### Wall Insulation
- [ ] Install batts in all wall cavities (Rockwool R-23 recommended - see cost comparison in Open Questions)
- [ ] Friction-fit, no gaps at edges or around wiring/boxes

### Roof Plane Insulation (hot roof - no attic ventilation)
- [ ] Install batts between truss top chords (R-15 Rockwool or R-13 fiberglass in 3.5" cavity)
- [ ] Hold in place with insulation support wire (zig-zag wire stapled between rafters)
- [ ] Optional: add 1-1.5" rigid foam board under rafters for extra R-value (~R-20 to R-23 total)
- [ ] Optional: install CertainTeed MemBrain smart vapor retarder under rafters (~$50-70 for whole ceiling, good insurance for hot roof)

### Interior Walls
- [ ] Install 1/2" CDX plywood on all walls (from Dunn order); paint if desired

### Floor Finish (optional - see Open Questions)
- [ ] Apply epoxy, sealer, or leave bare Advantech

---

## 16. Final Details

### Ventilation
- ~~Attic ventilation~~ - Not required: insulating at roof plane (unvented/hot roof assembly)
- [ ] Ensure air sealing is thorough at wall-to-roof connection
- [ ] Rely on mini-split / dehumidifier for interior moisture control

### Exterior
- [ ] Touch up paint/caulk
- [ ] Install address numbers if required
- [ ] Final grading for drainage away from shed
- [ ] Install splash blocks or gutters
- [ ] Install downspout extensions if needed

### Hardware & Security
- [ ] Seal all six sides of wood door (especially bottom edge) before installation — repaint/reseal every 3-5 years in PNW
- [ ] Install door locks
- [ ] Install any shelving brackets
- [ ] Install any wall-mounted storage

### Inspection & Documentation
- [ ] Schedule electrical inspection (required for permitted work)
- [ ] Document as-built dimensions
- [ ] Keep electrical permit and inspection records

---

## Materials Procurement Checklist

### Concrete & Foundation
- [ ] Concrete (4000 psi) - ~26 cf total for 6 piers (59 × 60-lb bags, or 64 with 10% waste)
- [ ] BigFoot form feet 25.5" (BF24) × 4 (corner piers)
- [ ] BigFoot form feet 29.5" (BF28) × 2 (center piers)
- [ ] Sonotubes 10" dia × 48" × 4 (corners, cut to length on site)
- [ ] Sonotubes 12" dia × 48" × 2 (centers, cut to length on site)
- [ ] GFRP (fiberglass) rebar #4 - ~12 lf total (one ~2' vertical bar per pier)
- [ ] Zip ties (for securing rebar to tube tops during pour)
- [ ] Simpson ABU66SS × 6 (all positions — beam saddle at east/center, post base at west)
- [ ] Simpson CC66 × 2 (west only — beam-to-post column caps)
- [ ] Titen HD screw anchors 5/8" × 6" (THDB62600H4SS) × 6 — purchased
- [ ] 1/2" × 7" SS hex bolts + nuts + washers × 12 sets (ABU66SS beam attachment) — purchased
- [ ] 5/8" × 8" HDG bolts + nuts + washers × 12 sets (CC66 beam/post attachment) — purchased
- [ ] Structural shims 1/2" plywood × 8 pcs (for ABU66SS, each side of beam at 4 positions)

### Framing Lumber (PT for ground contact)
- [ ] 6×6 PT posts - 2 pcs for west positions only (measure after pier cure)
- [ ] 2×10 PT × 16' × 4 (beam outer plies: 2 per beam × 2 beams)
- [ ] 3×10 PT × 16' × 2 (beam center ply: 1 per beam × 2 beams)
- [ ] 2×8 PT × 12' × 11 (field joists)
- [ ] 2×8 PT × 16' × 2 (rim joists)
- [ ] 2×8 PT blocking stock

### Framing Lumber (standard)
- [ ] 2×6 studs - count based on wall layout
- [ ] 2×6 plates - perimeter × 3 (bottom + double top)
- [ ] 2×4 truss stock
- [ ] 2×6, 2×8 header stock (only door opening, no windows)

### Hardware
- [ ] Simpson H2.5ASS hurricane ties × 26 (joist-over-beam uplift restraint — stainless)
- [ ] Simpson H2.5A hurricane ties × 18 (truss-to-top-plate — HDG)
- [ ] Simpson A35 × 48 (optional for blocking — alternative to toe-nailing)
- [ ] Simpson SD9 × 1-1/2" connector screws × 200 (truss ties) — purchased
- [ ] 1/2" × 6.5" HDG carriage bolts + nuts + washers × 16 sets (beam lamination) — purchased
- [ ] 3" × 0.131" HDG ring-shank framing nails (blocking, subfloor, wall sheathing, roof sheathing) — purchased
- [ ] 2" × 0.113" HDG ring-shank nails × 3,000 ct (truss gussets) — purchased
- [ ] 16d HDG smooth common nails (rim joists) — purchased
- [ ] 16d bright common nails (wall framing, lookouts) — purchased (short ~100, buy one more box)
- [ ] 3" SS ring-shank siding nails (HardiePlank)
- [ ] #8 × 3" SS deck screws (furring strips)

### Sheathing
- [ ] 3/4" T&G Advantech subfloor × 6 sheets
- [x] 7/16" Zip System roof sheathing × 10 sheets (purchased — Dunn order)
- [ ] 1/2" structural plywood for truss gussets × 2 sheets
- [x] 7/16" Zip System wall panels × 14 sheets (purchased — Dunn order, integrated WRB)

### Roofing
- [ ] Metal roofing panels (~200 sf)
- [ ] Ridge cap
- [ ] Eave/gable trim
- [ ] Roofing screws with washers
- [ ] Ice & water shield
- [ ] Synthetic underlayment
- [ ] Drip edge

### Siding & Exterior
- [ ] HardiePlank 8.25" cedarmill 12' planks — ~70 to start (all walls use 12' stock; buy more as needed)
- [ ] HardiePlank starter strip — 5 strips (12' each, covers 53 lf perimeter minus door)
- [ ] Aluminum outside corner pieces — 64 pcs (4 corners × 16 courses, sold individually)
- [ ] 1×3 furring strips × 8' — ~58 strips (rainscreen)
- [ ] Cor-A-Vent SV-3 bug screen — ~60 lf (base of rainscreen gap)
- [ ] Metal Z-flashing — ~60 lf (base of wall)
- [ ] Zip tape (Zip System seam tape)
- [ ] Tyvek (for sill/jamb flashing areas not covered by Zip panels)
- [ ] Door casing/trim — PVC or HardieTrim
- [ ] 3" SS ring-shank siding nails (~1,500 ct)
- [ ] #8 × 3" SS deck screws (~120 ct, furring strips)
- [ ] Caulk (exterior grade, paintable)
- [ ] Primer + paint (match house)

### Door (already purchased - wood man door)
- [ ] Flashing tape
- [ ] Metal drip cap
- [ ] Exterior casing (HardieTrim or match siding trim)
- [ ] Door hardware (lock, hinges if not prehung)
- [ ] Weatherstripping
- [ ] Threshold

### Insulation & Vapor
- [x] Wall insulation batts - Rockwool ComfortBatt R-23 15" × 10 packs ~398 sf (purchased; may need 1-2 more packs)
- [ ] Roof plane insulation batts - ~192 sf (Rockwool R-15 or fiberglass R-13)
- [x] Polyiso rigid foam for floor - Rmax ThermoSheath-3 3" R-20.3 foil-faced 4×8 sheets × 6 (purchased)
- [ ] Canned spray foam for sealing foam edges
- [x] 1/4" galvanized hardware cloth - 4'×25' rolls × 2 (purchased; ~200 sf coverage)
- [ ] Insulation support wire (for holding roof batts in place)
- [ ] Optional: CertainTeed MemBrain smart vapor retarder (~200 sf for roof plane)
- [ ] Optional: 1-1.5" rigid foam for under-rafter boost
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

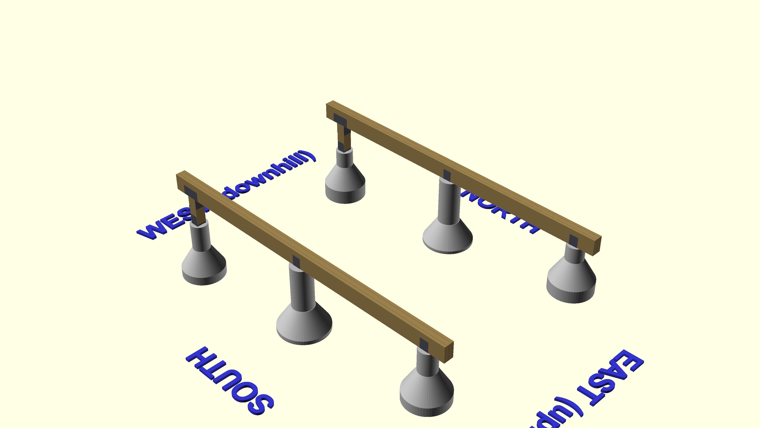
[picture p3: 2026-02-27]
renders/iso-posts-and-beams.png

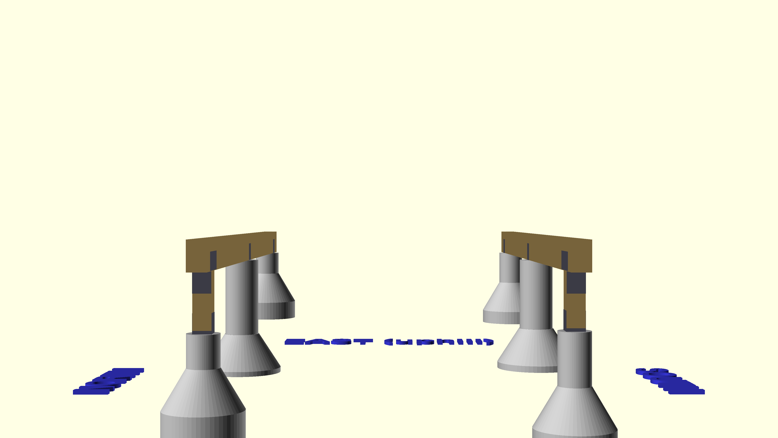
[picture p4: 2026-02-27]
renders/iso-beam.png

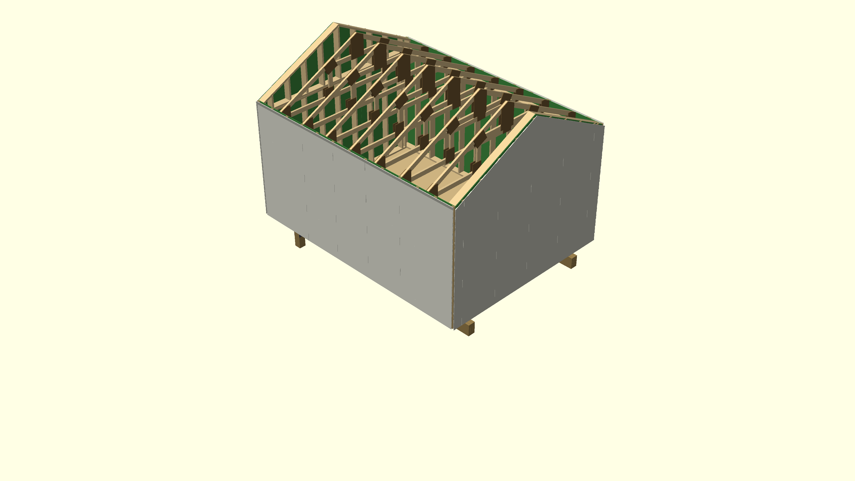
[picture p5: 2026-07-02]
renders/06-cladding.png

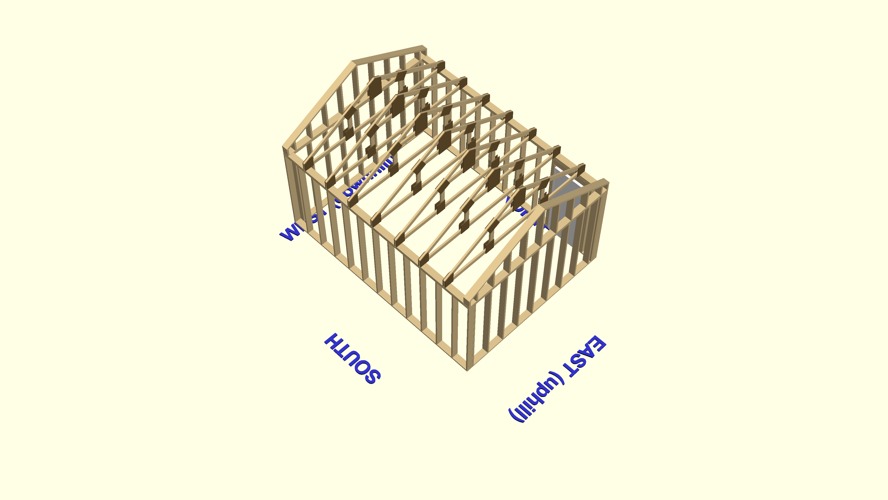
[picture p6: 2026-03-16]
renders/iso-roof-framing.png

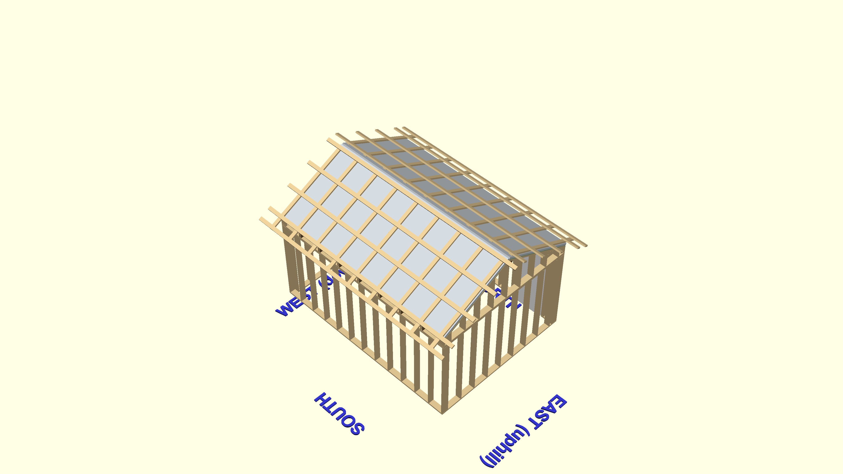
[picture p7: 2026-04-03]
renders/iso-eave-framing.png

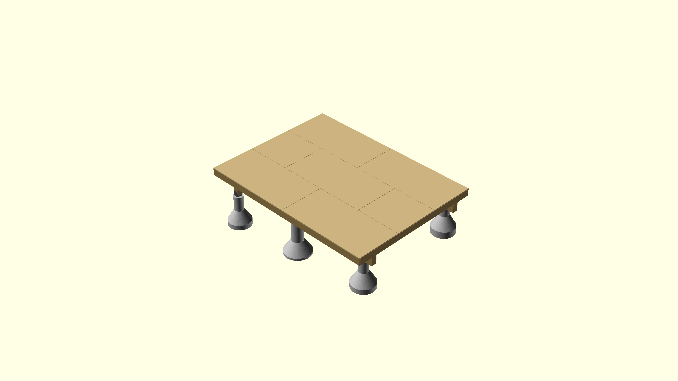
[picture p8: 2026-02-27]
renders/03-floor-deck.png

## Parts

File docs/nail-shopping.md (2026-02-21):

# Nail Shopping Guide

## Nail Type Matrix

| Type | Shank | Coating | Used For |
|---|---|---|---|
| **Common** | Thickest (0.131"–0.162") | Various | All structural connections — framing, sheathing, rim joists. "Common" = the right one when in doubt. |
| **Box** | Thinner than common | Various | Light framing, non-structural. Do NOT substitute for common in structural connections. |
| **Ring-shank** | Same diameter, rings cut into shank | Various | Better withdrawal resistance — subfloor, siding. Rings grip like a screw. |
| **Connector/Hanger** | Varies, short | SS or HDG | Specifically for Simpson ties and hangers. Short (1.5") so they don't blow through. |
| **Metal framing** | Thin (0.113") | Galvanized | For metal connector plates only — NOT a substitute for 8d common. Looks similar, wrong gauge. |
| **Sinker** | Between box and common, vinyl-coated | Plain | Easier to drive by hand. Not the same as common — don't substitute. |

### Coating Guide

| Coating | Abbrev | PT Contact? | Use |
|---|---|---|-----|
| Bright (plain steel) | — | No | Interior framing only (studs, plates, trusses) |
| Electro-galvanized | EG | No | Interior only — thin coating, ACQ corrodes it |
| Hot-dip galvanized | HDG | Yes | All PT lumber contact, exterior exposure |
| Stainless steel | SS | Yes | PT contact + fiber cement siding (alkaline) |

---

## Shopping List

### Still Needed — FastenersPlus.com (online — not at hardware stores)

| Item | Qty | Used For |
|---|-----|---|
| Simpson SSNA8D 8d × 1-1/2" 316 SS ring-shank connector nail, pkg 150 | 1 | §4 H2.5ASS joist ties — 130 short nails needed |
| Simpson SSA8D 8d × 2-1/2" 316 SS ring-shank connector nail, 1 lb tub (~94) | 2 | §4 H2.5ASS joist ties — 130 long nails needed |
| 3" × .131" 20-22° collated ring-shank nails, 304 SS, pkg 1000 | 2 | §16 HardiePlank siding — ~1,500 needed |

> Order before you need them — not available at HD/Lowe's.

### Still Needed — Hardware Store

| Item | Qty | Used For |
|---|-----|---|
| Grip-Rite 16d 3-1/2" Bright Smooth Common Nails, 1 lb | 1 | §8/§9/§14 — short ~100 nails |

---

### Purchased — Home Depot 2026-02-20

| Item | Purchased | Sections | Status |
|---|---|---|---|
| DeWalt 3" .131 Ring Shank HDG Framing Nails, 2,000 ct (DWRHS10DR131G) | 2 boxes = 4,000 | §6 blocking (144), §7 subfloor (600), §10 wall sheathing (1,200), §13 roof sheathing (700) | ✓ ~2,644 needed, 4,000 on hand |
| Grip-Rite 2" .113 Ring Shank HDG Framing Nails, 1,000 ct (GR04HG1M) | 3 boxes = 3,000 | §11 truss gussets (~2,500) | ✓ |
| Grip-Rite 16d 3-1/2" Bright Smooth Common Nails (1 lb + 2×5 lb) | ~11 lbs = ~517 | §8 bottom plate (42), §9 wall framing (250), §14 lookouts (128) | ⚠ short ~100 |
| Grip-Rite 16d 3-1/2" HDG Smooth Common Nails, 1 lb | 2 lbs = ~94 | §5 rim joists (78) | ✓ |
| Simpson SD9112 #9 × 1-1/2" SD Connector Screws, 100 ct | 2 packs = 200 | §12 H2.5A truss ties (180) — Simpson-approved nail substitute | ✓ |

> Note: 3" ring-shank was substituted for 2.5" smooth common in §6/§10/§13. Ring-shank is a deviation from IRC smooth-shank spec for structural sheathing diaphragm — acceptable for unpermitted build.

---

## Not On This List (already purchased or TBD)

- **ABU66 bolts/nuts/washers** — purchased 2026-02-19 McMaster-Carr
- **CC66 bolts/nuts/washers** — purchased 2026-02-19 McMaster-Carr
- **Beam lamination bolts/nuts/washers** — purchased 2026-02-19 McMaster-Carr
- **Titen HD screw anchors** — purchased 2026-02-19 Dunn Lumber
- **Simpson SD9112 connector screws** (§12) — purchased 2026-02-20 Home Depot
- **#8 × 3" SS deck screws** (§16 furring) — ~120, not yet purchased
- **Metal roofing fasteners** (§15) — TBD pending roofing profile selection

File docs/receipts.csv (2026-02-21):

Date | Vendor | Category | Product | Qty | Unit Price | Subtotal | Tax | Total
2026-02-02 | Home Depot | Layout | HDX 12oz Double Coverage Spray Paint White | 1 | 4.98 | 4.98 | 0.51 | 5.49
2026-02-02 | Home Depot | Layout | 250ft Mason Line Refill Polypro Pink | 1 | 3.97 | 3.97 | 0.41 | 4.38
2026-02-02 | Home Depot | Layout | Jute Twine #30x200 Natural Fiber | 1 | 4.80 | 4.80 | 0.49 | 5.29
2026-02-10 | Home Depot | Footings | 60lb Sakrete Concrete Mix | 15 | 4.55 | 68.25 | 7.10 | 75.35
2026-02-06 | Lowe's | Waste | 28in Bigfoot Concrete Footing Form | 2 | 29.98 | 59.96 | 6.30 | 66.26
2026-02-06 | Lowe's | Footings | 24in Bigfoot Concrete Footing Form | 4 | 28.48 | 113.92 | 11.96 | 125.88
2026-02-06 | Lowe's | Footings | Quikrete 12in Concrete Form Tube | 1 | 13.88 | 13.88 | 1.46 | 15.34
2026-02-06 | Lowe's | Footings | Quikrete 10in Concrete Form Tube | 2 | 9.98 | 19.96 | 2.10 | 22.06
2026-02-06 | Lowe's | Footings | 1/2in x 10ft Green Rebar | 2 | 10.21 | 20.42 | 2.14 | 22.56
2026-02-06 | Lowe's | Personal | Rockstar Punched 16oz | 1 | 3.08 | 3.08 | 0.32 | 3.40
2026-02-10 | Lowe's | Footings | 28in Bigfoot Concrete Footing Form | 2 | 29.98 | 59.96 | 6.29 | 66.25
2026-02-10 | Lowe's | Tools | 48in Heavy Duty I-Beam Level | 1 | 27.98 | 27.98 | 2.94 | 30.92
2026-02-10 | Lowe's | Tools | Johnson 16x24 Steel Framing Square Orange | 1 | 12.98 | 12.98 | 1.36 | 14.34
2026-02-10 | Lowe's | Hardware | Hex Washer Head Self-Tapping Screws #10x1 50ct | 1 | 6.98 | 6.98 | 0.73 | 7.71
2026-02-10 | Lowe's | Footings | Quikrete 60lb Concrete Mix | 9 | 4.55 | 40.95 | 4.30 | 45.25
2026-02-10 | Lowe's | Waste | Quikrete 60lb Concrete Mix | 6 | 4.55 | 27.30 | 2.87 | 30.17
2026-02-10 | Lowe's | Cleanup | 42-Gallon Contractor Trash Bags 24ct | 1 | 19.78 | 19.78 | 2.08 | 21.86
2026-02-11 | Home Depot | Footings | 60lb Sakrete Concrete Mix | 12 | 4.55 | 54.60 | 5.68 | 60.28
2026-02-11 | Home Depot | Footings | 60lb Sakrete Concrete Mix | 11 | 4.55 | 50.05 | 5.21 | 55.26
2026-02-11 | Home Depot | Footings | 60lb Sakrete Concrete Mix | 11 | 4.55 | 50.05 | 5.19 | 55.24
2026-02-11 | Home Depot | Personal | MTN Dew Code Red 20oz | 1 | 2.58 | 2.58 | 0.27 | 2.85
2026-02-11 | Sunbelt Rentals | Tool Rentals | Portable Electric Concrete Mixer Day Rental | 1 | 92.84 | 92.84 | 9.46 | 102.30
2026-02-12 | Home Depot | Tools | Husky 8in x 8in Steel Tamper | 1 | 39.98 | 39.98 | 4.16 | 44.14
2026-02-12 | Home Depot | Cleanup | HDX 32-Gallon Trash Can | 1 | 24.97 | 24.97 | 2.59 | 27.56
2026-02-12 | Home Depot | Personal | MTN Dew Code Red 20oz | 1 | 2.58 | 2.58 | 0.27 | 2.85
2026-02-16 | Dunn Lumber | Framing | Pressure Treated Hem/Fir 1x6-16' Utility Grade S4S | 15 | 17.28 | 259.20 | 26.94 | 286.14
2026-02-16 | Dunn Lumber | Framing | SPF 2x4-96" Premium Framing Stud #2&Btr KD S4S | 36 | 5.18 | 186.48 | 19.39 | 205.87
2026-02-16 | Dunn Lumber | Framing | SPF 2x4-12' Premium Framing Lumber Std&Btr KD S4S | 9 | 9.36 | 84.24 | 8.76 | 92.99
2026-02-16 | Dunn Lumber | Framing | SPF 2x6-96" Premium Framing Stud #2&Btr KD S4S | 48 | 7.08 | 339.84 | 35.33 | 375.17
2026-02-16 | Dunn Lumber | Framing | SPF 2x6-12' Premium Framing Lumber #2&Btr KD S4S | 6 | 14.16 | 84.96 | 8.83 | 93.79
2026-02-16 | Dunn Lumber | Framing | SPF 2x6-16' Premium Framing Lumber #2&Btr KD S4S | 6 | 18.88 | 113.28 | 11.78 | 125.06
2026-02-16 | Dunn Lumber | Siding | James Hardie HZ10 HardiePlank Lap Siding Cedarmill 5/16"x8-1/4"-12' | 80 | 15.88 | 1270.40 | 132.07 | 1402.47
2026-02-16 | Dunn Lumber | Framing | Pressure Treated 2x10-16' Premium Hem/Fir Ground Contact Cedar Toned | 4 | 47.68 | 190.72 | 19.83 | 210.55
2026-02-16 | Dunn Lumber | Framing | Pressure Treated Hem/Fir 3x12-16' Premium Ground Contact Cedar Toned | 2 | 135.68 | 271.36 | 28.22 | 299.58
2026-02-16 | Dunn Lumber | Framing | Pressure Treated 2x8-8' Premium Hem/Fir Ground Contact Cedar Toned | 5 | 16.64 | 83.20 | 8.65 | 91.85
2026-02-16 | Dunn Lumber | Framing | Pressure Treated 2x8-12' Premium Hem/Fir Ground Contact Cedar Toned | 13 | 27.36 | 355.68 | 36.98 | 392.66
2026-02-16 | Dunn Lumber | Framing | Pressure Treated 2x8-16' Premium Hem/Fir Ground Contact Cedar Toned | 2 | 36.48 | 72.96 | 7.59 | 80.55
2026-02-16 | Dunn Lumber | Framing | Pressure Treated Hem/Fir 6x6-8' Premium Ground Contact Cedar Toned | 1 | 50.24 | 50.24 | 5.22 | 55.46
2026-02-16 | Dunn Lumber | Sheathing | Advantech 3/4" OSB Underlayment T&G 4'x8' | 6 | 42.88 | 257.28 | 26.74 | 284.02
2026-02-16 | Dunn Lumber | Sheathing | Huber Zip System Zip Panel Roof/Wall Combo 4'x8'-7/16" | 24 | 25.88 | 621.12 | 64.57 | 685.69
2026-02-16 | Dunn Lumber | Insulation | Rmax 3" R-20.3 ThermoSheath-3 Foil Faced Polyiso Foam 4x8 | 6 | 106.88 | 641.28 | 66.67 | 707.95
2026-02-16 | Dunn Lumber | Insulation | Rockwool ComfortBatt R-23x15" Stone Wool Insulation 39.8sf | 10 | 87.88 | 878.80 | 91.38 | 970.18
2026-02-16 | Dunn Lumber | Sheathing | CDX 1/2" Plywood Sheathing 4-ply 4'x8' | 14 | 21.88 | 306.32 | 31.85 | 338.17
2026-02-16 | Dunn Lumber | Hardware | S.O. ABU66 Stainless Post Base | 6 | 241.25 | 1447.50 | 150.47 | 1597.97
2026-02-16 | Dunn Lumber | Hardware | S.O. H2.5A Stainless Hurricane Tie | 26 | 5.57 | 144.82 | 15.05 | 159.87
2026-02-16 | Dunn Lumber | Hardware | S.O. CC66 Painted Column Cap | 2 | 132.73 | 265.46 | 27.60 | 293.06
2026-02-16 | Dunn Lumber | Delivery | Delivery Charge | 1 | 60.00 | 60.00 | 6.24 | 66.24
2026-02-19 | Dunn Lumber | Waste | Simpson Mending Plate Galvanized 3x6 | 2 | 1.58 | 3.16 | 0.33 | 3.49
2026-02-19 | Dunn Lumber | Tools | Milwaukee Sawzall Flush Cut Reciprocating Saw Blade | 1 | 25.88 | 25.88 | 2.67 | 28.55
2026-02-19 | Dunn Lumber | Tools | Irwin Fluorescent Orange Chalk 8oz | 1 | 4.38 | 4.38 | 0.45 | 4.83
2026-02-19 | Dunn Lumber | Tools | Milwaukee 100ft Bold Line Chalk-N-Reel | 1 | 11.98 | 11.98 | 1.23 | 13.21
2026-02-19 | Dunn Lumber | Personal | Monster Energy Drink 16oz | 1 | 3.18 | 3.18 | 0.33 | 3.51
2026-02-19 | Dunn Lumber | Hardware | Simpson Titen HD Screw Anchor #304 Stainless Steel | 6 | 20.48 | 122.88 | 12.65 | 135.53
2026-02-19 | McMaster-Carr | Hardware | 316 SS Hex Head Screw 1/2"-13 x 7" (92186A738) | 12 | 4.37 | 52.44 | 5.45 | 57.89
2026-02-19 | McMaster-Carr | Hardware | 316 SS Washer 1/2" 0.531" ID 25ct (90107A033) | 1 | 10.24 | 10.24 | 1.06 | 11.30
2026-02-19 | McMaster-Carr | Hardware | 316 SS Hex Nut 1/2"-13 10ct (94804A340) | 1 | 4.71 | 4.71 | 0.49 | 5.20
2026-02-19 | McMaster-Carr | Hardware | 316 SS Hex Nut 1/2"-13 5ct (94819A055) | 1 | 3.22 | 3.22 | 0.33 | 3.55
2026-02-19 | McMaster-Carr | Hardware | HDG Hex Head Screw 5/8"-11 x 8" (95373A258) | 12 | 6.01 | 72.12 | 7.51 | 79.63
2026-02-19 | McMaster-Carr | Hardware | HDG Structural Washer 5/8" 0.688" ID 25ct (98119A035) | 2 | 8.38 | 16.76 | 1.74 | 18.50
2026-02-19 | McMaster-Carr | Hardware | HDG Hex Head Screw 1/2"-13 x 6-1/2" (95373A247) | 16 | 3.68 | 58.88 | 6.12 | 65.00
2026-02-19 | McMaster-Carr | Hardware | HDG Hex Nut 1/2"-13 50ct (90371A045) | 1 | 14.80 | 14.80 | 1.54 | 16.34
2026-02-19 | McMaster-Carr | Hardware | HDG Structural Washer 1/2" 0.531" ID 50ct (98119A033) | 1 | 9.68 | 9.68 | 1.01 | 10.69
2026-02-19 | McMaster-Carr | Hardware | HDG Hex Nut 5/8"-11 25ct (90371A050) | 1 | 11.99 | 11.99 | 1.25 | 13.24
2026-02-19 | McMaster-Carr | Shipping | McMaster-Carr Shipping | 1 | 42.01 | 42.01 | 4.37 | 46.38
2026-02-20 | Home Depot | Tools | Ryobi 18V 20-Degree Cordless Framing Nailer | 1 | 329.00 | 329.00 | 34.22 | 363.22
2026-02-20 | Home Depot | Tools | Ridgid Mini Palm Nailer | 1 | 79.00 | 79.00 | 8.22 | 87.22
2026-02-20 | Home Depot | Hardware | DeWalt 21° 3" .131 Ring Shank Galvanized Framing Nails 2000ct (DWRHS10DR131G) | 2 | 109.00 | 218.00 | 22.67 | 240.67
2026-02-20 | Home Depot | Hardware | Grip-Rite 2" .113 Ring Shank Galvanized Framing Nails 1000ct (GR04HG1M) | 3 | 46.58 | 139.74 | 14.53 | 154.27
2026-02-20 | Home Depot | Tools | Husky Adjustable Sawhorse | 2 | 79.98 | 159.96 | 16.64 | 176.60
2026-02-20 | Home Depot | Hardware | Galvanized Hardware Cloth 4x25' | 2 | 77.82 | 155.64 | 16.19 | 171.83
2026-02-20 | Home Depot | Hardware | Grip-Rite 16d 3-1/2" Bright Smooth Shank Common Nails 1lb (16C1) | 1 | 7.37 | 7.37 | 0.77 | 8.14
2026-02-20 | Home Depot | Hardware | Grip-Rite 16d 3-1/2" Bright Smooth Shank Common Nails 5lb (16C1) | 2 | 31.73 | 63.46 | 6.60 | 70.06
2026-02-20 | Home Depot | Hardware | Wood Shims | 2 | 1.78 | 3.56 | 0.37 | 3.93
2026-02-20 | Home Depot | Hardware | Grip-Rite 16d 3-1/2" Hot-Dipped Galvanized Smooth Shank Common Nails 1lb (16HGC1) | 2 | 8.55 | 17.10 | 1.78 | 18.88
2026-02-20 | Home Depot | Hardware | Simpson Strong-Tie #9 x 1-1/2" SD Strong Drive Structural Connector Screw 100ct (SD9112) | 2 | 16.33 | 32.66 | 3.40 | 36.06
2026-02-20 | Home Depot | Hardware | Simpson H2.5AZ 18ga Hurricane Ties (Truss/Top Plate) | 18 | 0.98 | 17.64 | 1.84 | 19.48
2026-02-20 | FastenersPlus | Hardware | 3" x .131" 20-22 Degree Collated Ring-Shank Nails 304 Stainless Steel 1000ct | 1 | 212.27 | 212.27 | 22.09 | 234.36
2026-02-20 | FastenersPlus | Hardware | Simpson SSA8D 8d x 2-1/2" Ring Shank Connector Nail 316 Stainless Steel 1lb | 2 | 24.12 | 48.24 | 5.01 | 53.25
2026-02-20 | FastenersPlus | Hardware | Simpson SSNA8D 8d x 1-1/2" Ring Connector Nail 316 Stainless 150ct | 1 | 27.92 | 27.92 | 2.90 | 30.82

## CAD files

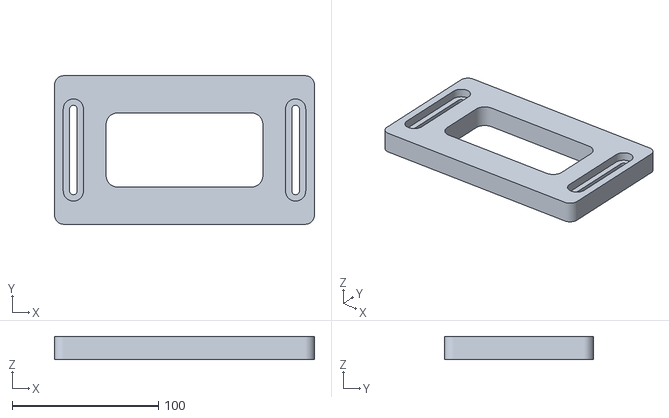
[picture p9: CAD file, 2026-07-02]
tools/hinge-template.stl
177.8 x 101.6 x 15.9

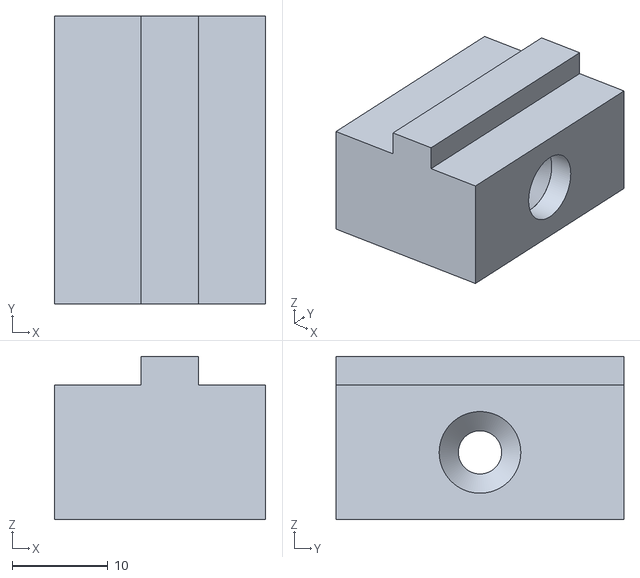
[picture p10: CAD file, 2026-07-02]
tools/screw-block.stl
22.0 x 30.0 x 17.0

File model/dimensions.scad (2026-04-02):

// Shed Model - Shared Dimensions and Constants
// All dimensions in inches unless noted

include <BOSL2/std.scad>

// ============================================
// DEFAULT TRANSPARENCY (overridden in shed_model.scad)
// ============================================
// These defaults let sub-files render standalone for previewing
//ground_alpha = 0.3;
//pier_alpha = 1.0;
//wood_alpha = 0.5;
//floor_alpha = 0.1;
//wall_alpha = 0.1;

// ============================================
// SHED DIMENSIONS (from README)
// ============================================
shed_length = 16 * 12;       // 16' = 192" (X direction, East-West)
shed_width = 12 * 12;        // 12' = 144" (N-S direction)

// Wall height - sized so 4×8 Zip panel covers:
//   below_floor + 87.25" wall + truss_end = 96"
// Truss end height = D + D/cos(angle) = 3.5 + 3.5/cos(26.57°) = 7.417"
// below_floor = 96 - 87.25 - 7.417 = 1.333"
wall_height = 87.25;
// wall_sheathing_below_floor computed after truss params are defined (see below)

// Door dimensions (east end of north wall)
// Measured frame: 31.5" wide × 76.5" tall, 6.75" thick, 29⅛" interior
// In-swing, hinge on right (viewed from exterior)
door_width = 31.5;           // Door frame outer width
door_height = 76.5;          // Door frame height (floor to top of frame)
door_rough_opening_extra = 1.5; // ¾" shim space each side
door_frame_thickness = 6.75; // Frame depth (into wall)
door_frame_side = (door_width - 29.125) / 2;  // 1.1875" side jamb thickness
door_interior_width = 29.125; // Interior clear width (29⅛")
door_slab_thickness = 1.75;  // Door slab thickness

// Post inset from edges
post_inset = 12;             // 1' inset from E/W edges

// Support positions along beam (from west edge, x=0)
// README: supports at 1', 8', 15' from EAST edge
// x=0 is west, x=192 is east
// - 15' from east = 1' from west = 12"   (west end - SHORT PIER, has post)
// - 8' from east = 8' from west = 96"    (center - TALL PIER, beam direct to concrete)
// - 1' from east = 15' from west = 180"  (east end - TALL PIER, beam direct to concrete)
support_x = [12, 96, 180];   // All support positions

// Which positions have vertical posts vs beam saddles
// As-built: East and center piers rise to beam level (no posts)
// Only west piers are short and need posts to reach the beam
post_positions = [12];               // West only - short pier, needs 6x6 post
saddle_positions = [96, 180];        // Center and East - tall pier, beam direct to concrete

// Beam positions (from south edge)
// README: Joists have 1.5' cantilever on each end, 9' main span
// Beams @ 1.5' and 10.5' from south edge (or 10.5' and 1.5' from north)
beam_y = [18, 126];          // 1.5', 10.5' = 18", 126"

// ============================================
// GROUND ELEVATION MAP
// ============================================
// Ground slopes per README: East=HIGH, West=LOW (28" drop over 16')
// Using arbitrary Z reference: East=52", West=24"
// X positions: 0, 64, 128, 192 (0', 5.33', 10.67', 16')
// Y positions: 0, 48, 96, 144 (0', 4', 8', 12')

// Calculate ground height at any point
// East side (x=192) = 52" (HIGH - uphill)
// West side (x=0) = 24" (LOW - downhill)
// North side is 2" lower than south (minor cross-slope)
function ground_height(x, y) =
    let(
        // Linear interpolation East-West: 24" at x=0 (west), 52" at x=192 (east)
        ew_height = 24 + (x / shed_length) * (52 - 24),
        // North-South adjustment (0 at y=0, -2 at y=144)
        ns_adjust = -(y / shed_width) * 2
    )
    ew_height + ns_adjust;

// Ground grid points (4x4)
ground_x = [0, 64, 128, 192];
ground_y = [0, 48, 96, 144];

// ============================================
// STRUCTURAL MEMBER SIZES
// ============================================
// 6x6 posts (actual 5.5" x 5.5")
post_width = 5.5;
post_depth = 5.5;

// Beams: 3-ply built-up 2x10 + 3x10 + 2x10 (per 2-beam.md)
// Creates 5.5" x 9.25" section (Hem-Fir #2 PT Incised)
// Connected with 1/2" x 6-1/2" HDG hex bolts, staggered top/bottom at 24" o.c., 8 per beam
// Utilization: 89% bending, 77% shear, 15% deflection
beam_height = 9.25;                // 2x10 actual depth
beam_outer_ply = 1.5;             // 2x10 outer plies (actual thickness)
beam_center_ply = 2.5;            // 3x10 center ply (actual thickness)
beam_total_thickness = 2 * beam_outer_ply + beam_center_ply;  // 5.5"

// Rim joists: 2x8 (match joists)
rim_thickness = 1.5;
rim_height = 7.25;

// Joists: 2x8 at 16" o.c. (per README structural analysis)
joist_thickness = 1.5;
joist_height = 7.25;         // 2x8 actual height
joist_spacing = 16;          // 16" on center
joist_length = shed_width - 2 * rim_thickness;  // 141" (12' minus two 1.5" rims)

// Joist layout: 16" o.c. from west end, short last bay at east
// West-most joist center at joist_thickness/2, stepping east
joist_x_west = joist_thickness/2;                         // 0.75"
joist_x_east = shed_length - joist_thickness/2;           // 191.25"
num_regular_joists = floor((shed_length - joist_thickness) / joist_spacing) + 1;  // 12 joists at 16" o.c.
num_joists = num_regular_joists + 1;                      // +1 for east-end short bay joist (13 total)

// Joist X positions: 12 at 16" o.c. from west, plus east-end closer
function joist_x(i) =
    (i < num_regular_joists)
        ? joist_x_west + i * joist_spacing
        : joist_x_east;

// Floor decking: 3/4" plywood
floor_thickness = 0.75;

// Wall framing: 2x6 at 16" o.c.
stud_thickness = 1.5;        // 2x6 actual thickness
stud_depth = 5.5;            // 2x6 actual depth
stud_spacing = 16;           // 16" on center
plate_thickness = 1.5;       // Top/bottom plate thickness
plate_depth = 5.5;           // Top/bottom plate depth

// Truss parameters
truss_member_width = 1.5;    // 2x4 actual thickness
truss_member_depth = 3.5;    // 2x4 actual depth
truss_overhang = 0;          // No N/S eave overhang (gable E/W overhang stays)
truss_pitch = 6/12;          // 6/12 pitch (rise per run)
truss_span = shed_width;     // 144" span between walls
truss_total_length = truss_span + 2 * truss_overhang;  // 168" total

// Derived truss dimensions
truss_half_span = truss_span / 2;                      // 72" from center to wall
truss_rise = truss_half_span * truss_pitch;           // 36" rise at peak
truss_rafter_angle = atan(truss_pitch);               // ~26.57 degrees

// Zip panel math: 4×8 sheet = below_floor + wall_height + truss_end_height
// Truss end vertical height at plumb cut = D + D/cos(angle)
truss_end_height = truss_member_depth + truss_member_depth / cos(truss_rafter_angle);
wall_sheathing_below_floor = 96 - wall_height - truss_end_height;  // ~1.337"

// Straining beam width (matches truss.js --sb-width=48)
straining_beam_width = 48;                            // 48" straining beam

// Queen post positions - SB butts against QP inside depth faces
// Formula from truss.js: qpInset = (span - sbWidth - qpDepth) / 2
queen_post_inset = (truss_span - straining_beam_width - truss_member_depth) / 2;  // 46.25"
queen_post_y = [queen_post_inset, truss_span - queen_post_inset];  // [46.25, 97.75]
queen_post_height = queen_post_inset * truss_pitch;  // 23.125" at queen post center

// Straining beam connects to rafter at different points than queen post tops
straining_beam_inset = (truss_span - straining_beam_width) / 2;  // 48"
straining_beam_z_above_chord = straining_beam_inset * truss_pitch;  // 24" above chord top


// ============================================
// PIER DIMENSIONS (from concrete.js as-built measurements)
// ============================================
// BigFoot form specs: [height, top_dia, base_dia, tube_dia]
bf_specs = [
    [12.25, 10,    24.5,  10],  // BF24 (corner piers)
    [12.25, 12.42, 28.25, 12],  // BF28 (center piers)
];

// Per-pier as-built data: [x_pos, y_pos, bf_index, above_cone, total_height]
// Positions mapped from concrete.js to model coordinates (x=0 west, x=192 east)
pier_specs = [
    [180, 126, 0,  9, 28.5],  // P1 - NE corner (1' from east, north beam)
    [180,  18, 0, 13, 30.5],  // P4 - SE corner (1' from east, south beam)
    [ 12, 126, 0, 10, 31.0],  // P3 - NW corner (15' from east, north beam)
    [ 12,  18, 0, 16, 33.5],  // P6 - SW corner (15' from east, south beam)
    [ 96, 126, 1, 27, 41.0],  // P2 - N center (8' from east, north beam)
    [ 96,  18, 1, 25, 39.5],  // P5 - S center (8' from east, south beam)
];

pier_above_ground = 2;       // Pier visibility above ground (post positions only)

// Post base height (Simpson ABU66 style)
post_base_height = 1;        // 1" above concrete for drainage

// ABU66SS post base / beam saddle
abu66ss_length = 5;          // 5" long (E-W, along beam)
abu66ss_width = 5.5;         // 5.5" wide (N-S, across beam)
abu66ss_height = 6.0625;     // 6-1/16" tall
abu66ss_base_h = 1;          // base portion height (~1")
abu66ss_gauge = 0.0897;      // 11-gauge steel ~0.090"
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

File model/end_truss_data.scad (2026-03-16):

// Auto-generated by generate-end-truss-data.js — do not edit by hand
// Run: node tools/generate-end-truss-data.js

// === CUT LIST (per end truss) ===
// Heights are bounding-box (long edge) — cut this length, then make the angle cut.
// Bottom Chord: 2x6 x 144.0" (12'-0.0") - Square cuts both ends
// South Rafter: 2x6 x 80.4" (6'-8.4") - Plumb cuts both ends
// North Rafter: 2x6 x 80.4" (6'-8.4") - Plumb cuts both ends
// South Fly Rafter: 2x6 x 80.4" (6'-8.4") - Plumb cuts both ends
// North Fly Rafter: 2x6 x 80.4" (6'-8.4") - Plumb cuts both ends
// End S filler: 2x6 x 6.3" (0'-6.3") - Short filler at eave
// End N filler: 2x6 x 6.3" (0'-6.3") - Short filler at eave
// Stud #0 (Y=8"): 2x6 x 9.9" (0'-9.9") - Angle cut top @ 26.6°
// Stud #1 (Y=24"): 2x6 x 17.9" (1'-5.9") - Angle cut top @ 26.6°
// Stud #2 (Y=40"): 2x6 x 25.9" (2'-1.9") - Angle cut top @ 26.6°
// Stud #3 (Y=56"): 2x6 x 33.9" (2'-9.9") - Angle cut top @ 26.6°
// Stud #4 (Y=72"): 2x6 x 41.1" (3'-5.1") - Angle cut top @ 26.6°
// Stud #5 (Y=88"): 2x6 x 33.9" (2'-9.9") - Angle cut top @ 26.6°
// Stud #6 (Y=104"): 2x6 x 25.9" (2'-1.9") - Angle cut top @ 26.6°
// Stud #7 (Y=120"): 2x6 x 17.9" (1'-5.9") - Angle cut top @ 26.6°
// Stud #8 (Y=136"): 2x6 x 9.9" (0'-9.9") - Angle cut top @ 26.6°

// Peak stud Y centers (shed coords, 16" o.c. aligned with E/W wall studs)
end_truss_stud_ys = [8.0000, 24.0000, 40.0000, 56.0000, 72.0000, 88.0000, 104.0000, 120.0000, 136.0000];
end_truss_gable_overhang = 12;

module end_truss_bottom_chord() {
    polyhedron(
        points = [
            [-2.75, 0.125, 0],
            [-2.75, 143.875, 0],
            [-2.75, 143.875, 1.5],
            [-2.75, 0.125, 1.5],
            [2.75, 0.125, 0],
            [2.75, 143.875, 0],
            [2.75, 143.875, 1.5],
            [2.75, 0.125, 1.5]
        ],
        faces = [
            [0,1,2,3],
            [7,6,5,4],
            [0,4,5,1],
            [2,6,7,3],
            [1,5,6,2],
            [0,3,7,4]
        ]
    );
}

module end_truss_south_rafter() {
    polyhedron(
        points = [
            [-2.75, 0, 7.2361],
            [-2.75, 71.9375, 43.2048],
            [-2.75, 71.9375, 44.8819],
            [-2.75, 0, 8.9131],
            [2.75, 0, 7.2361],
            [2.75, 71.9375, 43.2048],
            [2.75, 71.9375, 44.8819],
            [2.75, 0, 8.9131]
        ],
        faces = [
            [0,1,2,3],
            [7,6,5,4],
            [0,4,5,1],
            [2,6,7,3],
            [1,5,6,2],
            [0,3,7,4]
        ]
    );
}

module end_truss_north_rafter() {
    polyhedron(
        points = [
            [-2.75, 72.0625, 43.2048],
            [-2.75, 144, 7.2361],
            [-2.75, 144, 8.9131],
            [-2.75, 72.0625, 44.8819],
            [2.75, 72.0625, 43.2048],
            [2.75, 144, 7.2361],
            [2.75, 144, 8.9131],
            [2.75, 72.0625, 44.8819]
        ],
        faces = [
            [0,1,2,3],
            [7,6,5,4],
            [0,4,5,1],
            [2,6,7,3],
            [1,5,6,2],
            [0,3,7,4]
        ]
    );
}

module end_truss_south_fly_rafter() {
    polyhedron(
        points = [
            [-12.75, 0, 7.2361],
            [-12.75, 71.9375, 43.2048],
            [-12.75, 71.9375, 49.354],
            [-12.75, 0, 13.3853],
            [-11.25, 0, 7.2361],
            [-11.25, 71.9375, 43.2048],
            [-11.25, 71.9375, 49.354],
            [-11.25, 0, 13.3853]
        ],
        faces = [
            [0,1,2,3],
            [7,6,5,4],
            [0,4,5,1],
            [2,6,7,3],
            [1,5,6,2],
            [0,3,7,4]
        ]
    );
}

module end_truss_north_fly_rafter() {
    polyhedron(
        points = [
            [-12.75, 72.0625, 43.2048],
            [-12.75, 144, 7.2361],
            [-12.75, 144, 13.3853],
            [-12.75, 72.0625, 49.354],
            [-11.25, 72.0625, 43.2048],
            [-11.25, 144, 7.2361],
            [-11.25, 144, 13.3853],
            [-11.25, 72.0625, 49.354]
        ],
        faces = [
            [0,1,2,3],
            [7,6,5,4],
            [0,4,5,1],
            [2,6,7,3],
            [1,5,6,2],
            [0,3,7,4]
        ]
    );
}

module end_truss_end_stud_south() {
    polyhedron(
        points = [
            [-2.75, 0.125, 1.625],
            [-2.75, 1.625, 1.625],
            [-2.75, 1.625, 7.9236],
            [-2.75, 0.125, 7.1736],
            [2.75, 0.125, 1.625],
            [2.75, 1.625, 1.625],
            [2.75, 1.625, 7.9236],
            [2.75, 0.125, 7.1736]
        ],
        faces = [
            [0,1,2,3],
            [7,6,5,4],
            [0,4,5,1],
            [2,6,7,3],
            [1,5,6,2],
            [0,3,7,4]
        ]
    );
}

module end_truss_end_stud_north() {
    polyhedron(
        points = [
            [-2.75, 142.375, 1.625],
            [-2.75, 143.875, 1.625],
            [-2.75, 143.875, 7.1736],
            [-2.75, 142.375, 7.9236],
            [2.75, 142.375, 1.625],
            [2.75, 143.875, 1.625],
            [2.75, 143.875, 7.1736],
            [2.75, 142.375, 7.9236]
        ],
        faces = [
            [0,1,2,3],
            [7,6,5,4],
            [0,4,5,1],
            [2,6,7,3],
            [1,5,6,2],
            [0,3,7,4]
        ]
    );
}

module end_truss_stud_0() {
    polyhedron(
        points = [
            [-2.75, 7.25, 1.625],
            [-2.75, 8.75, 1.625],
            [-2.75, 8.75, 11.4861],
            [-2.75, 7.25, 10.7361],
            [2.75, 7.25, 1.625],
            [2.75, 8.75, 1.625],
            [2.75, 8.75, 11.4861],
            [2.75, 7.25, 10.7361]
        ],
        faces = [
            [0,1,2,3],
            [7,6,5,4],
            [0,4,5,1],
            [2,6,7,3],
            [1,5,6,2],
            [0,3,7,4]
        ]
    );
}

module end_truss_stud_1() {
    polyhedron(
        points = [
            [-2.75, 23.25, 1.625],
            [-2.75, 24.75, 1.625],
            [-2.75, 24.75, 19.4861],
            [-2.75, 23.25, 18.7361],
            [2.75, 23.25, 1.625],
            [2.75, 24.75, 1.625],
            [2.75, 24.75, 19.4861],
            [2.75, 23.25, 18.7361]
        ],
        faces = [
            [0,1,2,3],
            [7,6,5,4],
            [0,4,5,1],
            [2,6,7,3],
            [1,5,6,2],
            [0,3,7,4]
        ]
    );
}

module end_truss_stud_2() {
    polyhedron(
        points = [
            [-2.75, 39.25, 1.625],
            [-2.75, 40.75, 1.625],
            [-2.75, 40.75, 27.4861],
            [-2.75, 39.25, 26.7361],
            [2.75, 39.25, 1.625],
            [2.75, 40.75, 1.625],
            [2.75, 40.75, 27.4861],
            [2.75, 39.25, 26.7361]
        ],
        faces = [
            [0,1,2,3],
            [7,6,5,4],
            [0,4,5,1],
            [2,6,7,3],
            [1,5,6,2],
            [0,3,7,4]
        ]
    );
}

module end_truss_stud_3() {
    polyhedron(
        points = [
            [-2.75, 55.25, 1.625],
            [-2.75, 56.75, 1.625],
            [-2.75, 56.75, 35.4861],
            [-2.75, 55.25, 34.7361],
            [2.75, 55.25, 1.625],
            [2.75, 56.75, 1.625],
            [2.75, 56.75, 35.4861],
            [2.75, 55.25, 34.7361]
        ],
        faces = [
            [0,1,2,3],
            [7,6,5,4],
            [0,4,5,1],
            [2,6,7,3],
            [1,5,6,2],
            [0,3,7,4]
        ]
    );
}

module end_truss_stud_4() {
    polyhedron(
        points = [
            [-2.75, 71.25, 1.625],
            [-2.75, 72.75, 1.625],
            [-2.75, 72.75, 42.7361],
            [-2.75, 71.25, 42.7361],
            [2.75, 71.25, 1.625],
            [2.75, 72.75, 1.625],
            [2.75, 72.75, 42.7361],
            [2.75, 71.25, 42.7361]
        ],
        faces = [
            [0,1,2,3],
            [7,6,5,4],
            [0,4,5,1],
            [2,6,7,3],
            [1,5,6,2],
            [0,3,7,4]
        ]
    );
}

module end_truss_stud_5() {
    polyhedron(
        points = [
            [-2.75, 87.25, 1.625],
            [-2.75, 88.75, 1.625],
            [-2.75, 88.75, 34.7361],
            [-2.75, 87.25, 35.4861],
            [2.75, 87.25, 1.625],
            [2.75, 88.75, 1.625],
            [2.75, 88.75, 34.7361],
            [2.75, 87.25, 35.4861]
        ],
        faces = [
            [0,1,2,3],
            [7,6,5,4],
            [0,4,5,1],
            [2,6,7,3],
            [1,5,6,2],
            [0,3,7,4]
        ]
    );
}

module end_truss_stud_6() {
    polyhedron(
        points = [
            [-2.75, 103.25, 1.625],
            [-2.75, 104.75, 1.625],
            [-2.75, 104.75, 26.7361],
            [-2.75, 103.25, 27.4861],
            [2.75, 103.25, 1.625],
            [2.75, 104.75, 1.625],
            [2.75, 104.75, 26.7361],
            [2.75, 103.25, 27.4861]
        ],
        faces = [
            [0,1,2,3],
            [7,6,5,4],
            [0,4,5,1],
            [2,6,7,3],
            [1,5,6,2],
            [0,3,7,4]
        ]
    );
}
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

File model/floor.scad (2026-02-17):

// Shed Model - Floor Decking
include <dimensions.scad>

module plywood_sheet(width, depth) {
    echo(str("CUTLIST,Floor decking,PT 3/4\" plywood,1,", width, "\" x ", depth, "\""));
    color(color_plywood, floor_alpha)
        cuboid([width - sheet_gap, depth - sheet_gap, floor_thickness], anchor = BOTTOM);
}

module floor_decking() {
    floor_z = joist_bottom_z + joist_height;

    // Row 1 (South, y = 0-48") - above south beam - two full sheets
    translate([sheet_8ft / 2, sheet_4ft / 2, floor_z])
        plywood_sheet(sheet_8ft, sheet_4ft);
    translate([sheet_8ft + sheet_8ft / 2, sheet_4ft / 2, floor_z])
        plywood_sheet(sheet_8ft, sheet_4ft);

    // Row 2 (Center, y = 48-96") - half + full + half (staggered joints)
    translate([sheet_4ft / 2, sheet_4ft + sheet_4ft / 2, floor_z])
        plywood_sheet(sheet_4ft, sheet_4ft);  // West half sheet
    translate([sheet_4ft + sheet_8ft / 2, sheet_4ft + sheet_4ft / 2, floor_z])
        plywood_sheet(sheet_8ft, sheet_4ft);  // Center full sheet
    translate([sheet_4ft + sheet_8ft + sheet_4ft / 2, sheet_4ft + sheet_4ft / 2, floor_z])
        plywood_sheet(sheet_4ft, sheet_4ft);  // East half sheet

    // Row 3 (North, y = 96-144") - above north beam - two full sheets
    translate([sheet_8ft / 2, 2 * sheet_4ft + sheet_4ft / 2, floor_z])
        plywood_sheet(sheet_8ft, sheet_4ft);
    translate([sheet_8ft + sheet_8ft / 2, 2 * sheet_4ft + sheet_4ft / 2, floor_z])
        plywood_sheet(sheet_8ft, sheet_4ft);
}

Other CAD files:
model/foundation.scad
model/ground.scad
model/joists.scad
model/labels.scad
model/posts_and_beams.scad
model/purlins.scad
model/roof_polyiso.scad
model/roof_sheathing.scad
model/shed_model.scad
model/siding_data.scad
model/truss_data.scad
model/trusses.scad
model/wall_cladding.scad
model/walls.scad
tools/hinge-template.scad
tools/screw-block.scad

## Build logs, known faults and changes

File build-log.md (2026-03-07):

# Undated Pre-Work

Digging holes. Pouring concrete. Rental mud mixer was amazing. Destroyed two of the Bigfoot forms because I didn't test-fit both sizes. I cut off too many flanges on the larger size.

# 02/20/2026

Nail buying day. This SUCKED. Claude had specified unusual nail sizes. In retrospec, nails should be been specified with a minimum acceptable length and diameter, and a maximum length. Then we should have generated the minimum set of unique nails that satisified these criteria and gotten those in quantity.

# 02/23/2026
Material delivery day. Goal was to get everything moved from the driveway into the backyard. Stretch goal was get the brackets bolted into the ground.

# 02/24/2026

Day 1. Started on the north beam.

My goal for today was to get both beams set into the ground.

I got the north ABU66 brackets bolted into the concrete. Getting the brackets straight wasn't too bad using the laser.

I got the three layers of north beam set into the brackets, and I drilled and bolted the beam into the east and center ends. I broke my impact adapter that steps up to 1/2 inch while tightening the bolts. (I'll need a new adapter or a 1/2" impact, my air compressor just doesn't have the power to drive the air impact I have. The Ryobi impact is only $100.)

I cut the the post for the north side to the right length and I'm soaking the cut end in Copper Green Wood Preservative overnight.

The metal brackets hold everything so tight I can't slide the bracket and post into place under the beam, so I had to undo the bolts so I can lift the beam up and set the post under the bracket in order to hammer the beam down and set the beam and post into the saddles tightly.

End of day state: north beam set with 3 layers (and some nails to keep the boards aligned), north brackets bolted down, beam just secured with friction.
Goal for tomorrow: get north beam fully secured. Get south post cut and soak it overnight.

I expected the bolts for the beam lamination to arrive today, but tracking shows tomorrow, so I'm not behind yet.

# 02/25/2026

Day 2. Mostly a sick day with kid pickup and doctor appointment. Got one end of the south wood post set up to soak overnight. The bolts for beam lamination arrived.

# 02/26/2026

Day 3.

On the north beam, I struggled a lot getting straight holes through the wood beams. The holes would be slightly off and I struggled to get the bolt to thread out into the exit hole in the hardware. I think there's a technique where you drill a long hole from the exit side and then make a short, cone-shaped hole on the entry side that can find the exit hole. This gives the entrance side more flexibility in finding the hole, then it will hopefully follow the long hole out the desired position. The 5/8ths bolts are not really bendy at all though, so this is tough.

I was also stalling the 8amp drill I borrowed. The 5.5" PT beams are just too much wet material. I'd have to basically run a handful of rotations forward, then reverse to clear chips, then repeat. I'd use the 5/8" spade bit to basically ream out the holes and try to get a straighter through-hole between the hardware saddles.

On the south side, I had to pull the bolt and drill deeper on the southwest piller, the bolt hit 100 ft/lbs of torque and was still not all the way down. I think the hole just didn't go deep enough. I'm curious if that was the first one I drilled. I got all three boards set in the south brackets. I cut six shims to go under the south middle pier inside the saddle, it was just too short to have a level beam. This probably makes the bottom hole in the ABU66 too close to the edge of the beam on that pillar, so maybe we'll send a few nails through the extra holes in the bracket as backups.

I ended the day cutting the post for the south side to the correct length and set the newly cut end in copper to soak overnight.

The 21 degree stainless siding (framing) nails arrived. Expecting the SS joist hanger nails tomorrow.

End of day state: North beam fully bolted to the ABU66 and the bottom two bolts of the CC66 are installed. South ABU66 are torqued to the concrete, beam is set and leveled, and nailed to align the three boards. Post is cut and soaking.
Goal for tomorrow: get south beam fully secured. My technique is improving, so I'm optimistic.

# 02/27/2026, Friday

Day 4.

Getting bolts into beams. Based on the progress, I must have installed 4 bolts on the north, then 8 on the south side. They're tough so that probably was the full day.

The notable bit was getting the post set between the CC66 above and the ABU66 below. The brackets are turned opposite ways, so you can't slide it in with the beam in the final position. I used a car jack placed just west of the middle bracket to lift the beam up high enough I can fit the post it, then lower it back down. I used a piece of large dimension lumber I had sitting around as a sledge to pound the beam deep into the bracket.

End of day state: just 4 big bolts remaining, at the top of the CC66 to the south beam.

# 02/28/2026, Saturday

Day 5.

Just had a couple hours. First two bolts were perfect. The next two bolts were a bit of a struggle. But I had enough technique to get through quick.

Talking technique: the big auger bit just stalls. The drill I'm borrowing just doesn't have the torque to push through, and I think the chips from the wet pressure treated wood is compacting rather than ejecting. I can drill and back, but eventually the auger still gets stuck and it's a bear to withdraw. I'm mostly using a shorter spade bit. I use a short level, first as a square to make sure I'm lined up left/right, then to make sure I'm shooting up just a hair (thanks to a YouTube clip where someone pointed out the bit slopes down). When I'm lucky, I can hit the 5/8ths hole on the other side of the 5.5" beam.

But when I'm off? My bolts are long, so I have some threads to spare. I'm usually off by less than half the diameter. I don't have a bench grinder or I'd round the whole thing to have a point that would direct it out the hole. (I tried this technique... with a file clamped to a board, while spinning the bolt in my impact driver and holding the shaft with my leather gloves. I tried it once, it worked but... yikes.) The thing I settled on was using the jigsaw with a metal blade to cut the tip of the bolt at a 45 degree angle. Then turning the bolt so the angle allowed the narrower tip to slip into the exit hole and guide the rest of the bolt. It worked, repeatable and fast. The downside is it's galvanized metal, so I probably need to paint the exposed metal now. 

The bolts that have to thread the holes are done now.

The next bolts are just going through the beam to tie the layers together. I tried the auger, it stalled, got stuck and was a bear to extract. I used my smaller diameter bit for running cords through walls (3/8", 48" long). It's got a design that gives more room for chips behind it and the smaller diameter means less surface contact to overcome for the torque of the drill. This worked better, just a little bit of in and out at the beginning to clear a few chips, then it punches all the way through. Then I come back with the impact driver and spade bit and hit each side, clearing chips as I go with the air compressor from the opposite side.

The last battery died with 2 left to install on the south beam and 7 left on the north beam.

The other task I'd done earlier was trim the beams to exactly 16' and begin to trim the top of the beam. My two big batteries died pretty early in this task. One thing I noticed is that the wood I'm removing from the top of the beam wants to grab down on my blade, so I have to remove the offcut periodically. I wonder if just relief cross-cuts would be sufficient and faster. I don't need the offcuts, so creating this trash is fine.

End of day state: beams need tops trimmed flush, still need 9 more through-bolts to tie the beam together.
Goal for next day: Last bolts done, beams trimmed and painted with copper green.

# 03/01/2026, Sunday

(Likely little, I gotta get tax paperwork together. Will focus on using battery and getting stuff painted so it can dry. I can set the rim joists over the top of the beam so it doesn't get too wet on Tuesday, if I have to.)

Rented a recriprocating saw to cut the tops off the beam. It was killing my battery too fast to use my existing tools.

Joists all cut to length. Exposed ends and beam top all painted with Copper Green.

# 03/02/2026, Monday

Got all the blocking cut and painted with Copper Green. Nailed the joists to the rim. Tried to level the top of the beam on the north side a little with a detail sander.

Zip and truss plywood was delivered.

# 03/03/2026, Tuesday

Light enough rain that I got the joists fully secured to the beams. The palm nailer made quick work of the hurricane ties. Experimented with a way to cut the foam for the floor.

# 03/04/2026, Wednesday

Rain was too heavy to realistically do any work. I put a tarp over the structure to help keep the framing from getting any wetter.

# 03/05/2026, Thursday

Got some good work done on the floor. We cut majority of the insulation and nailed down the first floor panels.

# 03/06/2026, Friday

Finished cutting the insulation. However, we should have covered the floor panels last night. Just too much rain got down under the floor panels. I've covered it now with the tarp, but we'll need to use the shop vac to suck up the water before finishing the floor panels.

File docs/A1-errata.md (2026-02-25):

# A1 — Errata & Documentation Inconsistencies

Cross-referencing docs, receipts, cutlist, and code as of 2026-02-24.

All actionable items have been corrected. The following are informational notes only.

---

## Joist Lumber Quantities (informational)

| Source | 2×8 × 8' | 2×8 × 12' | 2×8 × 16' |
|---|---|---|---|
| `cutlist.csv` | 5 | 13 | 2 |
| `receipts.csv` | 5 | 13 | 2 |
| `3-joists.md` cut list | — | 11 (field) | 2 (rim) |

Receipts match cutlist. The joist doc says 11 field joists × 12' + 2 rim joists × 16' = 13 boards. The cutlist also has 5× 2×8-8' (blocking stock) and 2 extra 12' boards (spares/blocking). Not an error — just not explicitly documented in the joist doc's cut list.

---

## Pier Position Labels (informational)

All sources are consistent: P1=NE, P4=SE, P2=N center, P5=S center, P3=NW, P6=SW.

---

## Connector Nail Quantities (informational)

| Source | SSA8D (2.5") | SSNA8D (1.5") |
|---|---|---|
| `8-fasteners.md` §4 | Need: 130 long + 130 short | |
| `receipts.csv` | 2 × 1lb SSA8D (~188 nails) | 1 × 150ct SSNA8D |

Sufficient quantities purchased. The `8-fasteners.md` §4 formatting of "(155 @ $23.36)" and "(94 @ $24.12)" refers to per-tub counts and prices, not quantities purchased.

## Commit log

2026-02-15 saving state
    [dimensions.scad, floor.scad, foundation.scad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]
2026-02-15 rewrote truss code
    [truss_data.scad, trusses.scad]
2026-02-16 trusses complete enough
    [dimensions.scad, end_truss_data.scad, shed_model.scad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]
2026-02-17 updates with cutlist and fasteners
    [cutlist.csv, end_truss_data.scad, floor.scad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]
2026-02-17 updates for better sharing
    [shed_model.scad]
2026-02-19 fix bottom plate material: non-PT KD Hem-Fir, bright nails
    The shed is elevated on piers with no ground contact, so the wall
    bottom plate is standard KD Hem-Fir, not PT. Corrects nail spec from
    HDG to bright common and removes the two TODO comments.
2026-02-19 reorganize: move docs to docs/, move model generators to tools/
    [receipts.csv]
2026-02-19 fix CC66 post cap rendering: correct upper U orientation and beam interior clearance
    [dimensions.scad, foundation.scad, posts_and_beams.scad]
2026-02-19 next receipt
    [receipts.csv]
2026-02-19 add McMaster-Carr fastener order receipt and mark purchased in fastener schedule
    [receipts.csv]
2026-02-21 record nail purchases and assignments from 2026-02-20 Home Depot run
    [receipts.csv]
2026-02-21 fix siding nail quantity and wall area table
    - Nail spec updated: 5 lb box → 1 box (1000 ct), 3" x .131" collated SS ring-shank
    - Wall area table corrected to include gable peaks on E/W walls (96 → 114 sf each)
    - Total net siding area corrected from 430 → 466 sf
2026-02-21 clean up checklist follow-up responses section
    - Remove skirting correction, gravel pad, Z-flashing sections (per notes)
    - Replace XPS with polyiso throughout (Rmax ThermoSheath-3 3" R-20.3, purchased)
    - Correct hardware cloth install order: drops between joists first, foam rests on top
    - Mark wall insulation (Rockwool R-23 x10) and hardware cloth as purchased
    - Update corner trim to aluminum siding corners (to be purchased)
    - Move roof insulation details to docs/7-roof.md (was empty)
    - Move epoxy floor details to docs/9-finishings.md (new)
    - Move landing details to docs/10-stairs.md (new)
    - Update interior finish decision: 1/2" CDX over Rockwool, painted
2026-02-21 sync checklist with actual design decisions in docs/
    - Fix anchor type: Titen HD 5/8"x6" (not wedge anchors 1/2"x7")
    - Fix post cap: CC66 (not AC6SS) for west posts
    - Fix beam lamination: carriage bolts at 24" o.c. (not face-nails)
    - Lumber: 2x10+3x10+2x10 (not 2x12 pairs)
    - Fix floor framing: joist-over-beam with H2.5ASS hurricane ties
    - Remove nonexistent LUS28 joist hangers
    - 11 field joists + 2 rim joists (not 13x12')
    - Fix door R.O.: ~33" wide (not 38")
    - Add rainscreen layer to siding assembly (1x3 furring, Cor-A-Vent)
    - Fix siding: 6.25" exposure, all walls use 12' planks
    - Fix wall sheathing: Zip System panels (purchased, not plain OSB)
    - Update materials section to match all o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
2026-02-21 add FastenersPlus receipt 2/20: SS ring-shank nails and Simpson connector nails
    [receipts.csv]
2026-02-24 fix beam fastener refs: carriage bolt/GRK screws → HDG hex bolt
    All docs now consistently say "hex bolt" to match the McMaster
    purchase (95373A247, 1/2"-13 × 6-1/2" HDG hex head).
    [dimensions.scad]
2026-02-24 fix beam center ply (3x12 ripped) and section properties note
    cutlist.csv: 3x10 → 3x12 (rip to 9.25") to match actual purchase
    2-beam.md: "structural screws" → "through-bolts" in composite note
    [cutlist.csv]
2026-02-24 fix furring strip qty: 60 strips ripped from 15× PT 1x6-16'
    Reconciles cutlist (was 50), wall-layers doc (was 58), and actual
    purchase (15× 1x6-16' = 30 strips of 16' = 60 strips of 8').
    [cutlist.csv]
2026-02-24 replace OSB/Tyvek with Zip System throughout docs
    24 Zip panels purchased serve walls (~15) and roof (~10).
    Zip's integrated WRB eliminates Tyvek housewrap layer.
    Still need to purchase Zip tape and J-roller.
    [cutlist.csv]
2026-02-24 add H2.5AZ (18× galvanized) to cutlist for truss-to-plate ties
    SS ties for PT joist contact, HDG ties for non-PT truss contact.
    [cutlist.csv]
2026-02-24 fix Titen HD anchor: 6-1/2" → 6" to match purchase
    6.5" doesn't exist; 6" purchased (THDB62600H4SS) gives 5.64"
    embedment vs 5.5" nominal — still adequate.
2026-02-25 fix wall stud species: Hem-Fir → SPF #2 to match purchase
    SPF 2x6 studs were purchased (receipts.csv). truss.js already
    uses SPF #2 values (Fb=875) and passes at 54% — no concern.
2026-02-25 fix Advantech typo in cutlist; clean up errata to informational only
    All actionable errata items have been corrected.
    [cutlist.csv]
2026-02-27 add gusset plate calculator and truss data generation
    Add tools/gussets.js for optimizing gusset plate cuts from plywood sheets.
    Expand generate-truss-data.js with detailed geometry for OpenSCAD rendering.
    Update cutlist, model files, and build log through day 4.
    [cutlist.csv, dimensions.scad, shed_model.scad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]
2026-02-27 as-built post heights: south 16.5", north 17.25"
    Replace computed post heights with measured as-built values.
    Adjust beam_bottom_z from 60 to 45 to match real geometry.
    Position posts and pier tops from beam level down.
    [dimensions.scad, foundation.scad, posts_and_beams.scad]
2026-02-27 update render camera positions and remove iso-joist view
2026-03-04 no-overhang trusses, Zip wall sheathing, roof sheathing
    - Eliminate N/S eave rafter overhang (rafters flush with wall face)
    - Shorten wall_height to 87.25" for Zip envelope math
    - Wall Zip panels: 96" sheet = 1.34" below subfloor + 87.25" wall + 7.41" truss end
    - Door RO height 78 -> 77.25" (header flush with top plate, no cripples)
    - Add roof_sheathing.scad: 7/16" Zip on rafters, eave to ridge
    - Rafter length 93.9" -> 80.5" (no overhang)
    - Gable E/W overhang unchanged at 12"
    [dimensions.scad, end_truss_data.scad, roof_sheathing.scad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]
2026-03-04 remove gable overhangs, add gable peak sheathing and roof panel grid
    - Remove ladder framing (fly rafters, outriggers, lookouts)
    - Plumb-cut rafter ends at eave instead of perpendicular cuts
    - Shift end trusses inward so outer face is flush with wall
    - Add gable peak OSB sheathing (trapezoid/pentagon panels)
    - Add gable furring strips extending to rafter height
    - Roof sheathing now renders as 4x8 panel grid with gaps
    - Fix Zip color to green, fix furring strip Z-offset
    [dimensions.scad, end_truss_data.scad, roof_sheathing.scad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]
2026-03-06 fix sheathing in peaks, add wall cutlist tool
    [wall_cladding.scad]
2026-03-06 Add E/W wall stud install warning, update model and renders
    Wall cutlist: flag 2nd-to-last stud on E/W walls to be left out
    during ground assembly and toenailed in after wall is standing
    (no nailgun access between last two studs near north wall).
    Also includes model tweaks and updated render screenshots.
    [dimensions.scad, shed_model.scad, siding_data.scad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]
2026-03-06 Reorient roof sheathing per ZIP System specs, add cutlist output
    Orient panels with 8' edge along ridge (perpendicular to framing) and
    4' edge up the slope. Stagger alternating rows by 48". Add CUTLIST echo
    statements matching wall_cladding format.
    [roof_sheathing.scad]
2026-03-06 WIP: Rebuild end truss peak framing with 2x6 studs 16" o.c.
    Replaced irregular 2x4 studs and outriggers with 2x6 studs at 16" o.c.
    aligned with E/W wall studs below. All end truss members now 2x6.
    Stud orientation still needs fixing.
    [end_truss_data.scad]
2026-03-06 Reframe end trusses as second top plate for E/W walls
    - Rotate end truss studs 90° (1.5" face outward, 5.5" cavity in X)
    - Lay bottom chord and rafters flat (1.5" tall, 5.5" deep in X)
    - N/S walls: split top plate (full lower + shortened upper, 5.5" inset each end)
    - E/W walls: single top plate (end truss bottom chord acts as second)
    - Lower end truss placement by plate_thickness so chord sits as 2nd plate
    - Raise rafter bottom to align sheathing plane with regular truss rafters
    - Add end studs at wall lines to fill gap from thinner chord/rafter
    - Slide end trusses inward so outer face aligns with wall studs below
    [end_truss_data.scad, trusses.scad, walls.scad]
2026-03-07 Add print-friendly wall framing cut list (HTML + PDF)
2026-03-07 Add print-friendly truss reference sheets (HTML)
2026-03-14 Add print-friendly gusset plate cut list (HTML)
2026-03-16 Gable sheathing: center studs on ridge, trapezoid panels, fix E/W wall sheet height
    - End truss studs now center on ridge (Y=72") at 16" OC each direction
    (9 studs: 8, 24, 40, 56, 72, 88, 104, 120, 136) for gable sheathing joint
    - E/W wall Zip sheets stop at single top plate (not full 4x8)
    - Gable sheathing extends down from single top plate to cover bottom chord
    - Gable panels are trapezoids (short vertical edge at eave) not triangles
    - Fix gable OSB thickness to include cladding_gap like wall panels
    - Fix trusses.scad CUTLIST: 2x6 (not 2x4), dynamic stud list from generated data
    - Update truss-cutlist.html with new stud layout and dimensions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
    [end_truss_data.scad, shed_model.scad, trusses.scad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]
2026-03-16 Fix end truss stud heights: derive cut list from 3D geometry
    The stud cut list had a separate height calculation that didn't account
    for the board gap or pick the correct (taller) corner, causing south
    studs to be ~1/2" short and north studs ~1/4" short. Now the generator
    derives cut dimensions directly from the polyhedron profile, and the
    OpenSCAD CUTLIST echo uses the same bounding-box formula. Added a
    bin-packing verify script that imports from the generator (single
    source of truth). Updated HTML to match corrected values.
    [end_truss_data.scad, trusses.scad]
2026-03-17 more printer friendly truss cutlist
2026-03-26 Add purlin/overhang framing proposal (A3), resolve foam thickness
    - New A3-purlin-proposal.md: purlin layout, eave brackets, fly rafters,
    fascia, flashing details, materials list, and installation sequence
    - A2: resolve foam thickness as 2" polyiso (R-13.1) for IRC R806.5
    compliance in unvented assembly; update all references throughout
    - 7-roof.md: replace TBD above-deck assembly with decided polyiso spec,
    restructure insulation section with exterior + cavity breakdown
2026-03-26 Add polyiso, purlins, and eave framing to OpenSCAD model
    Three new toggleable layers per A3 proposal:
    - roof_polyiso.scad: 2" rigid foam on both slopes
    - purlins.scad: 5 purlins per slope (2x4 flat, 12" gable overhang)
    - eave_framing.scad: outriggers, sub-fascia, fly rafters, fascia, barge boards
    Replaces unused show_ladder_framing flag with show_eaves.
    Adds iso-polyiso, iso-purlins, iso-eave-framing render views.
    [dimensions.scad, eave_framing.scad, purlins.scad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]
2026-03-27 show more in default renders
    [shed_model.scad]
2026-03-29 Add metal roof plan and material specs documentation
2026-04-02 Replace purlin-only layout with batten+purlin grid, remove eave framing
    Battens (2x4 flat) run up the slope aligned with trusses, extending 12"
    past the wall for eave overhang. Purlins (2x4 flat) run E-W over battens
    in 5 rows per slope, butt-joined at center. This replaces the old
    horizontal-only purlins and the separate eave framing module (outriggers,
    fly rafters, fascia, barge boards).
    [dimensions.scad, eave_framing.scad, purlins.scad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]
2026-04-03 Fix north slope grid orientation and eave purlin edge alignment
    Mirror the grid for the north slope so the overhang extends past the
    north wall instead of above the ridge. Shift eave purlin upslope by
    half its width so its outer edge aligns with the batten end.
    [purlins.scad]
2026-07-02 Add siding installation guide (docs/13-siding.md)
    [hinge-template.scad, hinge-template.stl, screw-block.scad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]
2026-07-02 Model siding install details from docs/13-siding.md
    - 16-course layout: courses start 1/4in below the starter line (Zip
    bottom edge); top course rips at the top of the wall Zip on eave walls
    - Starter strip and bug mesh at the furring bottoms (show_siding_trim)
    - Metal outside corner caps, one per corner per course, 64 total
    - Eave-wall closure blocks under P4, one per batten bay on 3/4in
    standoff, top beveled 26.6 deg (show_closure_blocks); the ripped top
    course leans out against the block face
    - E/W gable siding courses continue up the triangle with pitch-cut ends,
    clipped 3/4in below the rake for the exhaust slot; gable furring stops
    at the same line
    - siding_plank rebuilt as an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
    [shed_model.scad, wall_cladding.scad]
2026-07-27 Spec PT-rated furring screws with 2.5-3.5 inch length range
    Furring screws only contact PT and Zip, never fiber cement, so an
    ACQ-rated coated screw is acceptable in place of stainless. Record the
    length range against the 1.19 inch layer buildup and note why the
    connection is screwed rather than nailed.
    Also corrects the section 16 quantity, which said 24 in. o.c. / ~120
    screws while the installation doc calls for 16 in. o.c. (~350 needed).
2026-07-31 Add siding-stock.js: bin-pack cut list onto stock lumber
    First-Fit Decreasing packing of the siding cut list onto stock of a
    given length, charging saw kerf for each cut after the first on a
    stick. Reads siding-cuts.tsv (3- or 4-column TSV) and reports the
    per-stick cutting plan, drop-offs, and total waste.
    [siding-cuts.tsv]
2026-08-08 siding-stock: labeled pieces and -1 unknown-length estimation
    Accept space- or tab-separated rows with an optional label (N1A, W2B) and
    an optional fraction, so "S1B 128" and "W1B 38 0 0" both parse.
    A length of -1 marks a piece that still needs measuring. Since walls are
    roughly vertical, the row's width is taken from the widest fully-known row
    on the same wall -- widest so a course interrupted by the door (north row 1)
    doesn't under-estimate. Estimated pieces are packed and flagged ~est with
    their derivation; anything that can't be inferred is listed as to-measure
    and left out of the packing.
    [siding-cuts-08-11.tsv, siding-cuts-12-15.tsv]
